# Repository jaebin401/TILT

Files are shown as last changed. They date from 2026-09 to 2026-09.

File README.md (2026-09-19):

# TILT

> Two-legged Iterative Locomotion Testbed

A compact 6-DoF biped robot platform for iterative locomotion experiments.

<p align="center">
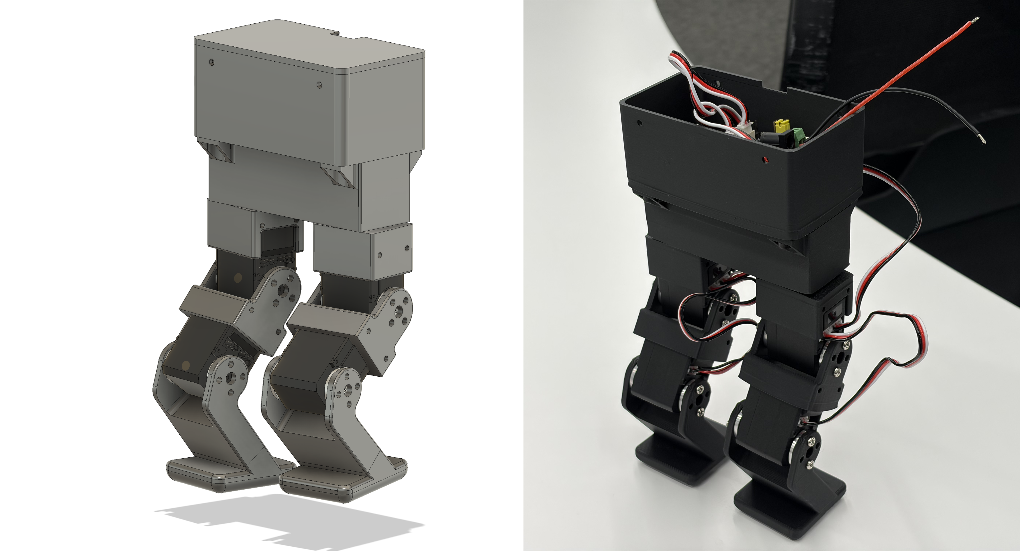
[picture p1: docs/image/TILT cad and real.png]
TILT MK1 CAD model
  
</p>

## Overview

TILT는 소형 이족보행 로봇의 기구 설계, 서보 제어, 보행 알고리즘을 반복적으로 실험하기 위한 로봇 프로젝트입니다.

Apple Developer Academy Challenge 6의 Physical AI Pet 프로젝트에서 보행 가능성을 검증하기 위해 시작했지만, 특정 캐릭터에 종속되지 않는 독립적인 로봇 플랫폼으로 발전시키는 것을 목표로 합니다.

## Goals

- ESP32-S3 기반 실시간 로봇 제어
- STS3215 버스 서보를 이용한 6자유도 하체 구현
- 모델 기반 관절 궤적과 보행 시퀀스 개발
- 평평한 실내 바닥에서 전진, 정지, 재출발 및 완만한 회전
- CAD와 펌웨어를 함께 관리하는 재현 가능한 로봇 프로젝트 구축
- 향후 센서 피드백과 균형 제어를 추가할 수 있는 구조 마련

## Hardware

| Component | Specification |
| --- | --- |
| Controller | ESP32-S3 |
| Actuator | 6 × Feetech STS3215-C001 |
| Servo interface | Waveshare Bus Servo Adapter (A) |
| Degrees of freedom | 6 DoF, 3 per leg |
| Communication | UART, BLE |
| Current prototype | TILT-P0 |

## Repository Structure

```text
TILT/
├── CAD/          # Mechanical source files and manufacturing exports
├── firmware/     # ESP32-S3 firmware
├── hardware/     # BOM, wiring, pinout and power documentation
├── tools/        # Servo setup and gait development utilities
└── docs/         # Architecture, assembly, calibration and experiment notes
```

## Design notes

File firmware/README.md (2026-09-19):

# TILT Firmware

TILT의 ESP32-S3 펌웨어 구조와 각 디렉토리의 책임을 정의합니다.

현재 단계에서는 모듈의 경계만 먼저 정리하며, ESP-IDF 프로젝트 설정과 C++ 구현은 이후 작업에서 추가합니다.

## Directory Structure

```text
firmware/
├── main/                       # 애플리케이션 진입점과 모듈 조립
├── components/
│   ├── tilt_core/              # 공통 타입과 로봇 설정
│   │   └── include/tilt/core/
│   ├── tilt_motion/            # 모델 기반 보행과 관절 목표 생성
│   │   └── include/tilt/motion/
│   ├── tilt_sts3215/           # STS3215 버스 서보 통신
│   │   └── include/tilt/sts3215/
│   ├── tilt_sg90/              # SG90 PWM 출력
│   │   └── include/tilt/sg90/
│   ├── tilt_safety/            # 명령 검증과 안전 상태 관리
│   │   └── include/tilt/safety/
│   ├── tilt_actuators/         # 액추에이터 명령 분배와 실행
│   │   └── include/tilt/actuators/
│   └── tilt_expression/        # 귀와 팔의 동작 생성
│       └── include/tilt/expression/
└── tests/
    ├── host/                   # 하드웨어 없이 실행하는 테스트
    └── hardware/               # 실제 ESP32와 액추에이터를 사용하는 테스트
```

각 컴포넌트의 공개 헤더는 `include/tilt/<component>/`에 둡니다. 구현 파일과 컴포넌트별 CMake 설정은 해당 컴포넌트의 루트에 배치합니다.

## Component Responsibilities

### `main`

펌웨어의 진입점입니다. 컴포넌트를 초기화하고 실행 태스크를 시작합니다.

하드웨어 제어나 보행 로직을 직접 구현하지 않고, 필요한 모듈을 조립하는 역할만 담당합니다.

### `tilt_core`

다른 컴포넌트가 함께 사용하는 타입과 설정을 정의합니다.

- 관절 식별자
- 관절 목표값과 현재 상태
- 관절별 위치 및 속도 제한
- 오류 코드
- 로봇 전체 설정

ESP-IDF의 UART, PWM 같은 하드웨어 기능에 의존하지 않는 것을 원칙으로 합니다. 각도 단위는 라디안, 시간 단위는 초를 기본으로 사용합니다.

### `tilt_motion`

TILT의 모델 기반 보행을 계산하고 다리 관절의 목표값을 생성합니다.

- LIPM과 같은 단순화된 동역학 모델
- CoM과 ZMP 기준값 계산
- 다리의 순기구학과 역기구학
- 보행 단계와 지지 상태 관리
- swing foot 궤적 생성
- MPC 또는 단순화된 궤적 추종 제어

초기에는 하나의 컴포넌트로 관리하며 구현이 커지면 내부를 `model`, `kinematics`, `planning`, `control` 영역으로 나눕니다. 물리 모델과 제어기의 경계가 충분히 커질 경우 별도 컴포넌트로 분리할 수 있습니다.

이 컴포넌트는 하드웨어를 직접 제어하지 않습니다. 계산 결과를 `JointTarget`으로 출력하고 안전 계층에 전달합니다.

### `tilt_sts3215`

ESP32-S3와 Waveshare Bus Servo Adapter 사이의 UART 통신과 STS3215 프로토콜을 담당합니다.

- 패킷 인코딩과 디코딩
- 서보 위치, 속도, 가속도 명령
- 현재 위치와 상태 읽기
- 통신 오류와 응답 시간 초과 처리

서보의 raw position과 레지스터 주소는 이 컴포넌트 밖으로 노출하지 않습니다.

### `tilt_sg90`

SG90 서보를 구동하기 위한 PWM 출력을 담당합니다.

- 각도와 PWM duty 변환
- 출력 범위 제한
- 귀와 팔에 연결된 채널 관리

표정이나 제스처의 의미는 해석하지 않고, 전달받은 목표 각도만 실행합니다.

### `tilt_safety`

액추에이터로 전달되기 전의 모든 명령을 검증하고 로봇의 안전 상태를 관리합니다.

- 관절 위치 및 속도 제한
- 비정상 수치와 오래된 명령 거부
- 급격한 목표값 변화 제한
- `Disarmed`, `Armed`, `Fault` 상태 관리
- 오류 발생 시 안전 정지와 fault latch

보행, 귀, 팔을 포함한 모든 움직임은 이 계층을 통과해야 합니다.

### `tilt_actuators`

검증된 관절 목표값을 실제 액추에이터 드라이버로 전달합니다.

- 다리 관절은 `tilt_sts3215`로 전달
- 귀와 팔 관절은 `tilt_sg90`으로 전달
- 하드웨어 초기화와 출력 주기 관리
- 액추에이터 상태 수집

여러 태스크가 드라이버를 동시에 호출하지 않도록 실제 하드웨어 접근의 단일 진입점 역할을 합니다.

### `tilt_expression`

귀와 팔을 이용한 자세, 제스처, 동작 시퀀스를 생성합니다.

이 컴포넌트는 PWM을 직접 출력하지 않고 논리적인 관절 목표값을 생성합니다. 생성한 목표값은 안전 검증을 거쳐 `tilt_actuators`로 전달됩니다.

## Command Flow

```text
Gait command                  Expression command
     │                                │
     ▼                                ▼
tilt_motion                  tilt_expression
     │                                │
     └─────────── JointTarget ────────┘
                      │
                      ▼
             tilt_safety validation
                      │
                      ▼
              tilt_actuators routing
                  │           │
                  ▼           ▼
         tilt_sts3215     tilt_sg90
                  │           │
                  ▼           ▼
              Leg servos   Ear / arm servos
```

상위 로직은 하드웨어 드라이버를 직접 호출하지 않습니다. `JointTarget`을 생성하고 안전 계층과 액추에이터 관리 계층을 통해서만 움직임을 요청합니다.

## Dependency Rules

```text
tilt_core
├── tilt_sts3215
├── tilt_sg90
├── tilt_safety
├── tilt_motion
└── tilt_expression

tilt_actuators
├── tilt_core
├── tilt_safety
├── tilt_sts3215
└── tilt_sg90

main
└── application components
```

- `tilt_core`는 다른 TILT 컴포넌트에 의존하지 않습니다.
- 드라이버는 상위 제어 로직에 의존하지 않습니다.
- `tilt_safety`는 특정 액추에이터 드라이버에 의존하지 않습니다.
- 컴포넌트 사이에서는 공개 헤더만 사용합니다.
- 순환 의존성을 만들지 않습니다.

## Tests

### `tests/host`

일반 컴퓨터에서 실행할 수 있는 순수 로직 테스트를 둡니다. 단위 변환, 명령 제한, 상태 전이와 같이 실제 하드웨어가 필요하지 않은 기능을 우선 검증합니다.

### `tests/hardware`

ESP32-S3와 실제 액추에이터가 필요한 검증 코드를 둡니다. 테스트마다 필요한 배선, 전원 조건, 실행 순서와 예상 결과를 함께 기록합니다.

## Planned Extensions

센서 피드백과 iPhone 연동을 구현할 때 다음 컴포넌트를 같은 원칙으로 추가합니다.

- `tilt_estimation`: IMU와 관절 피드백을 이용한 상태 추정
- `tilt_ble`: iPhone 명령 수신과 텔레메트리 전송

새 컴포넌트는 책임과 공개 인터페이스가 정해진 뒤 디렉토리를 추가합니다.

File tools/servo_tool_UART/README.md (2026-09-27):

# TILT 서보 셋업 / 캘리브레이션 툴

`tilt_config.h` 의 TODO 항목을 실측으로 채우는 도구. 모든 결과는 **그대로 붙여넣을 수 있는 C 코드**로 출력된다.

| config 항목 | 채우는 툴 |
|---|---|
| `ZERO_TICK[]` | `j` 정밀 조그 → `z` |
| `JOINT_SIGN[]` | `s` 회전 부호 판별 |
| `JOINT_LIMIT[]` | `l` 가동범위 탐색 |
| `SERVO_UART_BAUD` | `b` 보레이트 스캔 |

## 위치

```
TILT/
├── firmware/
│   └── components/
│       ├── tilt_config/
│       └── tilt_sts3215/
└── tools/
    └── servo_tool_UART/     ← 이 프로젝트
```

루트 `CMakeLists.txt` 의 `EXTRA_COMPONENT_DIRS` 가
`../../firmware/components` 를 가리키므로, 이 디렉토리에서 바로 빌드하면
공용 컴포넌트가 딸려 온다.

## 빌드

```bash
cd tools/servo_tool_UART
idf.py set-target esp32s3
idf.py -p /dev/tty.usbmodemXXXX flash monitor
```

`Ctrl + ]` 로 모니터 종료.

## tilt_sts3215 연결 방식

```cpp
tilt::sts3215::Sts3215Bus bus{config};
bus.initialize();
bus.ping(id);
bus.readPosition(id, tick);
bus.writePosition(id, tick, speed);
bus.setTorque(id, enabled);
bus.setBaudRate(baud);
```

`main.cpp` 상단의 얇은 래퍼가 기존 도구 호출을 이 실제 API로 연결한다.

## 저장 정책

**진실 공급원은 `tilt_config.h` 하나뿐이다.**

NVS 는 캘리브레이션 도중 리셋·정전으로 작업이 날아가지 않게 하는 임시 스크래치일 뿐이다.
부팅 시 NVS 값이 있으면 그걸 쓰고 그 사실을 로그로 알린다.

캘리브레이션이 끝나면:
1. 출력된 배열을 `tilt_config.h` 에 붙여넣고
2. `c` 로 NVS 스크래치를 비운다

이 두 단계를 하지 않으면 "코드에 적힌 값"과 "로봇이 실제로 쓰는 값"이 갈라진다.

## 영점 잡는 순서

1. **`s` 부호 판별** — 먼저 해야 조그 화면의 DH theta 부호가 맞게 나온다
2. **`o` 엔코더 모니터** — 토크를 풀고 손으로 대략 영점 자세를 만든 뒤 `z`
3. **`j` 정밀 조그** — FINE(1 tick = 0.088deg)로 마무리, DH theta 가 0.00 에 수렴하면 `z`
4. **`0` zero pose 이동** — config 의 `[0, -20, +20]` 으로 이동해 검증
   - 발판이 지면과 평행한가
   - 접지점이 Hip Yaw 축 바로 아래(x=0)인가
   - 지면 ~ torso 원점 높이가 약 104mm 인가
5. **`l` 가동범위 탐색** — 마지막에. 영점이 확정돼야 각도 값이 의미를 가진다

### 각 관절의 DH theta = 0 자세

| 관절 | 영점 자세 |
|---|---|
| Hip Yaw | 발끝이 정면(+x) |
| Hip Pitch | 허벅지가 수직 |
| Knee Pitch | 정강이가 허벅지와 일직선 |

`zero pose` 인 `[0, -20, +20]` 과 혼동하지 말 것. 영점은 **DH theta = 0** 인 자세이고,
zero pose 는 거기서 허벅지를 20deg 앞으로 기울이고 무릎을 20deg 굽힌 **운용 기본자세**다.

### DH + 방향

| 관절 | + 방향 |
|---|---|
| Hip Yaw | 발끝이 왼쪽으로 |
| Hip Pitch | 다리가 뒤로 스윙 |
| Knee Pitch | 무릎이 굽음 |

좌우 다리 모두 같은 정의를 쓴다. 거울 반전은 `JOINT_SIGN` 이 흡수한다.

## 안전

- 서보 전원은 손 닿는 곳에 두고, 언제든 끌 수 있게 한다
- `space` = 전체 토크 OFF (어느 화면에서든)
- 부팅 시 절대 위치 명령을 보내지 않는다 — 현재 위치를 READ 해서 기준으로만 삼음
- `s` 부호 판별과 `0` zero pose 이동은 **공중에 매단 상태**에서 할 것
- `l` 가동범위 탐색은 다리끼리 부딪히기 직전까지만. 스탠스 폭이 72.4mm 라 Hip Yaw 안쪽 여유가 적다

## 툴 목록

| 키 | 기능 |
|---|---|
| `p` | ID 스캔 (0~253) |
| `b` | 보레이트 스캔 |
| `j` | 정밀 조그 (q/a w/s e/d = 왼쪽, r/f t/g y/h = 오른쪽, `m` 스텝 토글, `i` 상태표, `z` 영점 확정) |
| `o` | 토크 해제 + 엔코더 실시간 모니터 (`z` 로 영점 확정) |
| `l` | 가동범위 탐색 → `JOINT_LIMIT` 출력 |
| `s` | 회전 부호 판별 → `JOINT_SIGN` 출력 |
| `0` | zero pose 로 천천히 이동 |
| `v` | 현재 작업값 배열 전부 출력 |
| `c` | NVS 스크래치 비우기 |
| `t` | 전체 토크 ON/OFF 토글 |
| `h` | 메뉴 |
| `space` | 비상정지 |

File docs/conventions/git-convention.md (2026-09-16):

# TILT Git Convention

## 1. Branch Strategy

TILT는 다음 브랜치 구조를 사용한다.

```text
feat/*  ──┐
fix/*   ──┤
docs/*  ──┼── Pull Request ──> dev ── Release PR ──> main
chore/* ──┤
test/*  ──┘
```

### main

조립, 시연 또는 배포할 수 있는 안정 상태를 보관한다.

- 직접 Push하지 않는다.
- `dev`에서 생성한 Pull Request만 병합한다.
- 펌웨어 빌드와 필요한 하드웨어 검증을 통과해야 한다.
- TILT MK 버전 또는 주요 마일스톤 단위로 갱신한다.
- Force Push하지 않는다.

### dev

다음 안정 버전을 준비하는 통합 브랜치다.

- 모든 작업 브랜치는 최신 `dev`에서 생성한다.
- 작업 브랜치의 Pull Request를 통해 변경을 반영한다.
- 직접 Push와 Force Push를 지양한다.
- 통합 후 정상 동작이 확인되면 `main`으로 Release PR을 생성한다.

### 작업 브랜치

| Prefix | 용도 | 예시 |
| --- | --- | --- |
| `feat/` | 새로운 기능이나 기구 추가 | `feat/servo-zero-position` |
| `fix/` | 기존 동작 또는 설계 오류 수정 | `fix/servo-id-conflict` |
| `docs/` | 문서 작업 | `docs/assembly-guide` |
| `chore/` | 저장소 설정과 개발 환경 | `chore/platformio-setup` |
| `test/` | 하드웨어, 제어 방식 또는 설계 실험 | `test/gait-sequence` |

브랜치 이름은 영문 소문자와 하이픈을 사용한다.

한 브랜치에서는 하나의 명확한 작업만 진행한다.

`test/*` 브랜치는 실험 결과를 검증하고 정리하기 위한 브랜치다. 실험 결과를 제품 코드에 반영하려면 불필요한 임시 코드를 제거한 뒤 `dev`를 대상으로 Pull Request를 생성한다. 폐기한 실험은 결과와 판단 근거만 문서로 남길 수 있다.

## 2. Standard Workflow

작업을 시작하기 전에 최신 `dev`를 가져온다.

```bash
git switch dev
git pull --ff-only origin dev
git switch -c feat/servo-zero-position
```

작업 후 원격 저장소에 Push한다.

```bash
git push -u origin feat/servo-zero-position
```

Pull Request 방향은 다음과 같다.

```text
base: dev
compare: feat/servo-zero-position
```

병합된 작업 브랜치는 삭제한다.

## 3. Commit Convention

기본 형식:

```text
<type>(<scope>): <subject>
```

예시:

```text
feat(firmware): add servo ping command
feat(cad): add MK1 hip bracket
fix(firmware): prevent duplicate servo IDs
docs(hardware): document servo wiring
chore(repo): configure initial repository
```

### Type

| Type | 의미 |
| --- | --- |
| `feat` | 새로운 기능, 동작 또는 기구 추가 |
| `fix` | 잘못된 동작이나 설계 수정 |
| `refactor` | 동작 변화 없는 코드 구조 개선 |
| `docs` | 문서 추가 및 수정 |
| `test` | 테스트 추가 및 수정 |
| `chore` | 저장소, 빌드, 개발 환경 설정 |
| `revert` | 기존 변경 되돌리기 |

### Scope

| Scope | 적용 대상 |
| --- | --- |
| `firmware` | ESP32-S3 펌웨어 |
| `cad` | 기구 설계 원본과 출력 파일 |
| `hardware` | 배선, 전원, BOM |
| `tools` | 서보 설정과 보행 개발 도구 |
| `docs` | 일반 문서 |
| `repo` | 저장소 전체 설정과 구조 |

### Subject 규칙

- 영어로 작성한다.
- 소문자로 시작한다.
- 동사 원형으로 시작한다.
- 문장 끝에 마침표를 사용하지 않는다.
- 가능하면 72자 이내로 작성한다.
- `update`, `change`, `work`처럼 모호한 표현만 사용하지 않는다.
- 하나의 Commit에는 하나의 논리적 변경만 포함한다.

## 4. Pull Request

Pull Request 제목도 Commit과 같은 형식을 사용한다.

```text
feat(cad): add MK1 hip bracket
fix(firmware): prevent servo overtravel
```

본문에는 다음 내용을 작성한다.

```markdown
## 작업 내용

- 무엇을 구현하거나 수정했는지 작성한다.

## 변경사항

- 주요 파일과 구조 변경을 작성한다.

## 확인 사항

- [ ] 관련 빌드 또는 파일 열기 성공
- [ ] 실제 하드웨어 또는 CAD 동작 확인
- [ ] 관련 없는 파일이 포함되지 않음
- [ ] 임시 파일과 빌드 결과물이 포함되지 않음

## 참고 자료

- 사진, 영상, 관련 문서 또는 이슈
- 없다면 `없음`
```

가능하면 다른 작업자 한 명이 검토한 후 병합한다.

작업 브랜치에서 `dev`로 병합할 때는 `Squash and merge`를 사용한다.

`dev`에서 `main`으로 승격할 때는 `Create a merge commit`을 사용한다.

## 5. Verification

### Firmware

- 프로젝트가 정상적으로 빌드되는가
- 서보 ID와 보드 설정이 올바른가
- 관절 제한을 벗어나는 명령이 없는가
- 실제 장비 테스트 결과를 PR에 기록했는가

### CAD

- 원본 파일이 정상적으로 열리는가
- STEP 또는 3MF로 정상적으로 내보낼 수 있는가
- 부품 간 간섭을 확인했는가
- 출력 방향과 revision을 확인했는가

### Repository

- 빌드 결과물과 개인 설정이 포함되지 않았는가
- `.DS_Store`와 임시 파일이 포함되지 않았는가
- 비밀번호, 토큰 또는 개인 환경 설정이 포함되지 않았는가

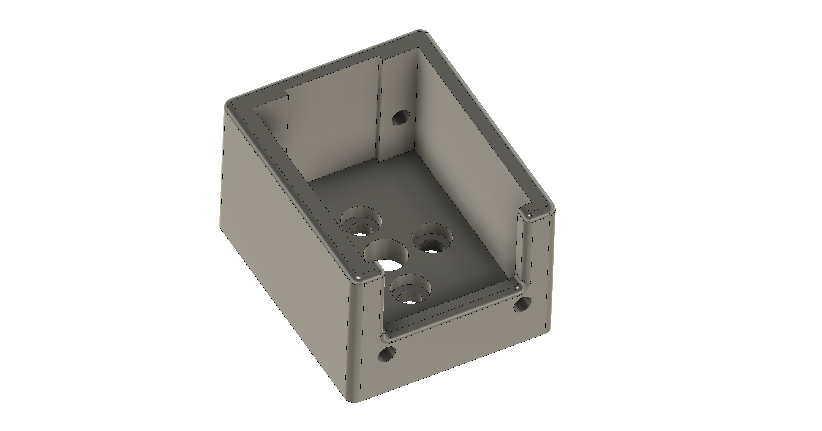
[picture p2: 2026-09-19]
CAD/images/hip pitch mount.png

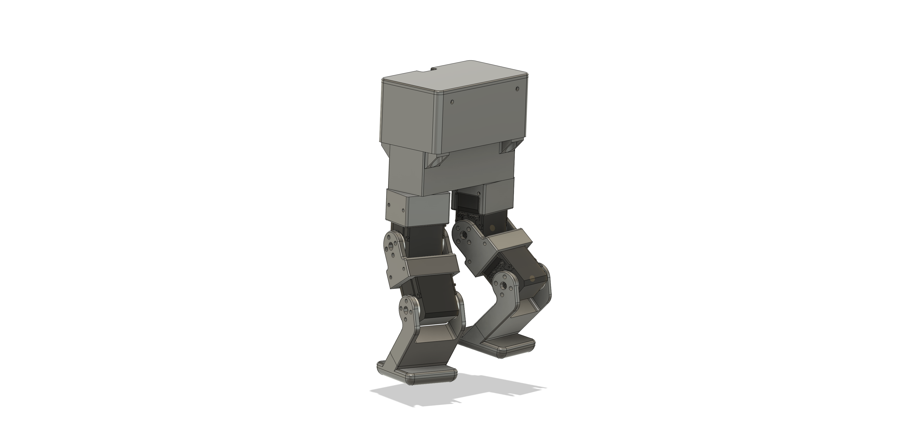
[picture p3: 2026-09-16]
docs/image/TILT mk1.png

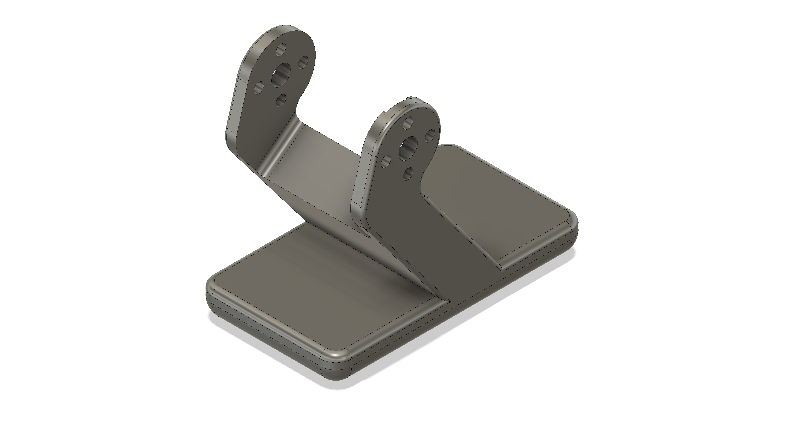
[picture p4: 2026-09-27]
CAD/images/calf-foot v3.png

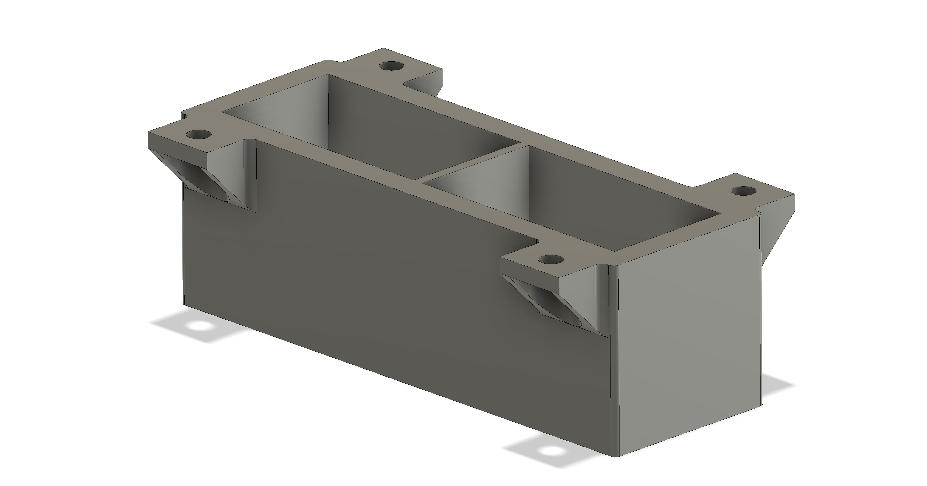
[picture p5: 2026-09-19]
CAD/images/hip yaw mount.png

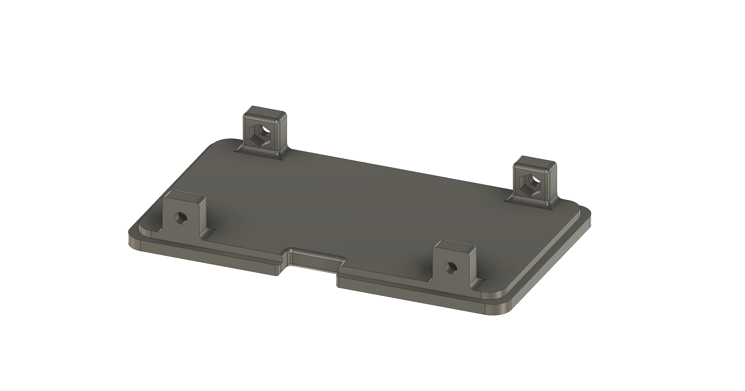
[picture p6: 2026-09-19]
CAD/images/torso lid.png

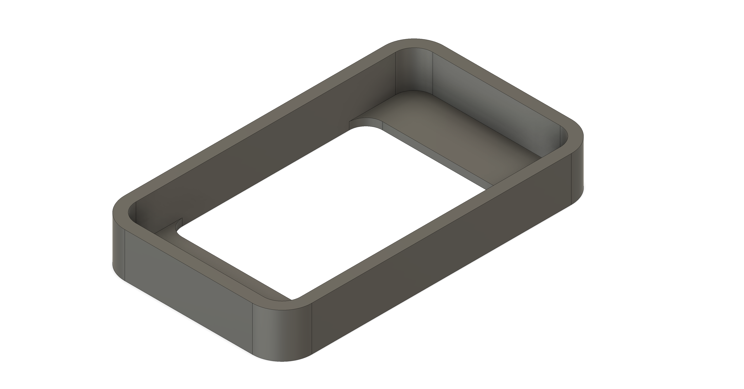
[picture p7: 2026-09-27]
CAD/images/calf-foot sharpener.png

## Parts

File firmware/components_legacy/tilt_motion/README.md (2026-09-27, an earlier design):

# TILT Motion

`tilt_motion`은 하드웨어와 독립적으로 여섯 다리 관절의 Pose와 시간 기반 Motion Clip을 계산합니다.

## Responsibility

- 논리 관절각 기반 `JointPose` 정의
- 확정된 기본자세 제공
- 두 Pose 사이의 부드러운 위치·속도·가속도 궤적 계산
- 여러 키프레임으로 구성된 Motion Clip 샘플링
- 임의의 시작자세에서 Home Pose로 복귀하는 표준 Motion 제공
- torso 좌표계에서 발의 위치·속도·가속도 궤적 계산
- Hip부터 Ankle 고정점까지의 FK·도달 가능 검사·closed-form IK
- Double Support와 좌우 Swing의 무상태 보행 phase 계산
- 지지 Ankle을 고정한 단일 Biped Step 궤적 계산

이 컴포넌트는 서보 ID, STS3215 raw position, 캘리브레이션 오프셋, 좌우 모터 방향 반전, UART 또는 실제 명령 실행을 다루지 않습니다. 이러한 변환과 실행은 actuator 및 driver 계층의 책임입니다.

## Joint order

모든 각도는 라디안이며 Robot/Kinematics 논리 좌표계를 사용합니다.

| Index | Joint |
| ---: | --- |
| 0 | LEFT_HIP_YAW |
| 1 | LEFT_HIP_PITCH |
| 2 | LEFT_KNEE_PITCH |
| 3 | RIGHT_HIP_YAW |
| 4 | RIGHT_HIP_PITCH |
| 5 | RIGHT_KNEE_PITCH |

## Home Pose

ADR-008에서 확정한 각 다리의 기본자세 `[0°, -20°, +20°]`를 사용합니다.

```text
[0, -0.349066, +0.349066, 0, -0.349066, +0.349066] rad
```

좌우 다리는 같은 논리 부호를 사용합니다. 실제 모터의 대칭 방향은 driver 계층에서 처리합니다.

## Interpolation

`samplePoseTransition()`은 quintic smootherstep `6u⁵ - 15u⁴ + 10u³`을 사용합니다. 시작과 끝에서 속도와 가속도가 모두 0이고 내부 상태가 없으므로, 호출 순서와 관계없이 임의 시각을 동일하게 샘플링할 수 있습니다.

반환되는 `PoseSample`에는 다음 값이 함께 들어 있습니다.

- 논리 관절 위치 `pose.angle_rad`
- 논리 관절 속도 `velocity_rad_per_sec`
- 논리 관절 가속도 `acceleration_rad_per_sec2`
- 전체 Motion 완료 여부 `finished`

`sampleMotionState()`는 첫 구간을 `initial_pose`에서 첫 키프레임까지 보간하고 이후 키프레임을 순서대로 연결합니다. 마지막 구간 이후에는 마지막 Pose와 0 속도·0 가속도를 반환합니다. 위치만 필요한 호출자는 `interpolatePose()`와 `sampleMotion()` 편의 함수를 사용할 수 있습니다.

`sampleReturnHomeMotion()`은 아직 실제 제한이 검증되지 않은 임의 Pose를 추가하지 않고, 문서로 확정된 Home Pose까지의 궤적만 생성하는 첫 표준 Motion입니다. 이동 시간은 호출자가 지정합니다.

## Foot trajectory

`sampleFootTrajectory()`는 torso 좌표계(`x=전진`, `y=왼쪽`, `z=위`)에서 시작점과 목표점 사이를 이동합니다. 수평·기준 높이 이동은 quintic smootherstep을 사용하고, `clearance_mm`만큼의 상승과 하강도 각각 quintic으로 계산해 시작·정점·착지에서 속도와 가속도가 0이 되도록 합니다.

보폭, 발을 드는 높이와 이동 시간은 하드웨어 검증 전이므로 라이브러리에 임의 상수로 고정하지 않습니다. 호출자가 게이트 파라미터로 전달해야 하며, `clearance_mm = 0`이면 지지발의 torso 기준 이동에도 사용할 수 있습니다. 이 출력은 다음 단계의 IK 입력이며 그 자체로 관절 명령이 아닙니다.

## Leg kinematics

`forwardAnkleKinematics()`와 `inverseAnkleKinematics()`는 ADR-008의 `Hip Yaw → Hip Pitch → Knee Pitch` 체인에서 Ankle 고정점 O4까지 계산합니다. `tiltLegGeometry()`는 확정된 Hip y 오프셋 `±36.2 mm`와 허벅지·정강이 길이 `50 mm`를 제공합니다.

IK는 호출자가 지정한 Hip Yaw 평면 안에서 양(+)의 Knee 굽힘 해를 계산합니다. 목표점이 해당 평면 밖에 있거나 두 링크의 작업공간 밖이면 `std::nullopt`를 반환합니다. 따라서 뒤쪽 목표도 Hip Yaw를 180°로 뒤집지 않고 지정된 다리 평면 안에서 처리할 수 있습니다.

Ankle FK/IK API는 O4까지만 계산해 확정된 링크 모델과 접지점 가정을 분리합니다. 접지점 E가 필요한 호출자는 아래의 별도 `ContactKinematics`를 사용합니다.

`forwardRobotAnkleKinematics()`와 `inverseRobotAnkleKinematics()`는 이 계산을 좌우 여섯 관절의 `JointPose` 단위로 묶습니다. 이를 통해 하드웨어 없이 `JointPose → 양쪽 O4 위치 → JointPose` 왕복 오차를 검증할 수 있습니다.

`ContactKinematics`는 다음 작업을 진행하기 위해 ADR-008의 Home Pose O4 위치와 문서상 접지점 E를 이용해 `O4→E=(-17.101007, 0, -7.015366) mm`를 임시로 역산합니다. 이 값은 CAD 실측값이 아니며 `provisionalFootContactGeometry()` 한 곳에 격리되어 있습니다. 현재 값으로 Home Pose 접지점과 `JointPose ↔ 양쪽 접지점` 왕복 계산을 재현하며, 실측 후 해당 상수만 교체합니다.

## Gait phase

`sampleGaitPhase()`는 `Double Support → 첫 번째 Swing → Double Support → 반대쪽 Swing`을 한 cycle로 반복합니다. 현재 지지 상태, 스윙 다리, 다음 스윙 다리와 phase 내부 진행률을 반환하며 내부 상태를 갖지 않습니다. Double Support와 Swing 지속 시간 및 첫 스윙 다리는 호출자가 전달하므로, 아직 검증되지 않은 주기나 좌우 시작 순서를 라이브러리에 고정하지 않습니다.

`sampleBipedStep()`은 전달받은 양쪽 O4 위치 중 지지 Ankle을 고정하고 스윙 Ankle에 `sampleFootTrajectory()`를 적용합니다. 위치·속도·가속도를 모두 반환하며, 결과 위치는 `inverseRobotAnkleKinematics()`로 관절 Pose 변환과 도달 가능 여부를 확인할 수 있습니다.

`sampleBipedStepPose()`는 이 경로를 한 번에 실행해 `발 궤적 → IK → JointPose`를 반환합니다. Cartesian 목표가 해당 Hip Yaw 평면이나 링크 작업공간을 벗어나면 관절각을 임의로 clamp하지 않고 실패합니다.

실제 보행 계획용 `sampleContactStep()`과 `sampleContactStepPose()`는 같은 동작을 접지점 E 기준으로 수행합니다. 지지 접지점을 고정하고 스윙 접지점만 이동한 뒤, 임시 접지점 기하를 포함한 IK로 `JointPose`를 계산합니다.

유효하지 않은 duration, NaN, 무한대 또는 잘못된 Clip은 `std::nullopt`로 거부합니다. 이 계층의 출력은 이후 Adapter가 `JointTargetBatch`로 변환하고 Safety 검증을 통과해야 실제 액추에이터로 전달될 수 있습니다.

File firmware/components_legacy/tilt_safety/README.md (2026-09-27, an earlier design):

# TILT Safety

## Responsibility and coordinates

`tilt_safety` validates six-joint commands before actuator execution and maintains Safety/Fault state. `JointTargetBatch.angle_rad` contains Robot/Kinematics logical joint angles in radians:

| Index | Logical joint |
| --- | --- |
| 0 | LEFT_HIP_YAW |
| 1 | LEFT_HIP_PITCH |
| 2 | LEFT_KNEE_PITCH |
| 3 | RIGHT_HIP_YAW |
| 4 | RIGHT_HIP_PITCH |
| 5 | RIGHT_KNEE_PITCH |

Motor Zero and Robot Zero are different coordinates. STS3215 raw position 2047 represents Motor Zero, not a logical robot target. Servo ID mapping, raw-position conversion, calibration offsets, servo direction/mirroring, UART, and STS3215 protocol belong below Safety. Safety does not generate trajectories or execute actuator commands. The actual TILT joint position and velocity limits have not been measured/configured here; host tests use synthetic values only.

## Implemented behavior

- Position and required-average-velocity validators check all six joints atomically. One invalid joint fails the entire validation. Targets are neither clamped nor automatically modified.
- The velocity validator checks `abs(target - runtime_reference) / (duration_ms / 1000)` in rad/s. This is the required **average** velocity, not measured instantaneous servo velocity. Time-based firmware calculations use seconds; `JointTargetBatch` retains its agreed millisecond fields.
- E-STOP and `FaultReason` (`EmergencyStop`, `ServoCommunication`) use a latched bitmask. Undefined, zero, and combined reason values are ignored by the public Fault APIs.
- A reported Fault enters `SafetyState::Fault`, invalidates the boot reference, and blocks new commands. A condition-cleared report alone does not remove the Fault. Explicit recovery is also required; clearing the final Fault returns to `Disarmed`, never directly to `Armed`.
- `initializeBootReference()` stores a validated logical joint-position snapshot. A boot snapshot indicates initialization readiness; it is not the current-position reference supplied to velocity validation during motion. Fault recovery does not restore it. A fresh physical read and initialization are needed after recovery.
- `arm()` succeeds only from `Disarmed` when position limits, velocity limits, and a validated boot reference are all present. `disarm()` revokes execution permission but never clears a Fault.
- While `Armed`, the runtime-reference overload returns `Accepted` only after the target and current runtime reference are both inside all six position limits and the required-average-velocity check passes. The overload without a runtime reference always rejects.

`SafetyState::Fault` does not itself mean a servo has physically stopped. The integrated pose test performs best-effort torque-off through the actuator driver; a physical power cutoff remains necessary when communication has failed.

## Pending work

| Area | Status and missing contract |
| --- | --- |
| Joint acceleration limit | **BLOCKED:** signed current velocity, velocity trajectory, acceleration/deceleration ramp, and execution guarantee |
| Actual boot position read | **INTEGRATED FOR TEST:** `esp32_pose_test` reads all six STS3215 positions and maps raw feedback to logical radians before arming; physical calibration remains pending |
| Safe initial pose | **INTEGRATED FOR TEST:** current-position hold precedes torque-on, then Home is reached through the normal Motion/Safety/Actuator path; completion tolerance and physical validation remain pending |
| Servo communication watchdog | **PARTIAL:** pose execution faults and requests torque-off on a failed read/write; a periodic background watchdog and measured thresholds remain pending |
| Stale command rejection | **CONTRACT PENDING:** `timestamp_ms` clock domain, stamping point, current-time provider, and maximum age |
| Command stream timeout | **BLOCKED:** Armed/active-motion and INIT execution semantics, stream requirement, and threshold |
| Over-temperature and overload | **BLOCKED:** telemetry fields and units, thresholds, sampling, and hardware validation; existing Fault mechanism can be reused once reasons are defined |

## Testing and concurrency

`firmware/tests/host/` tests pure position/velocity validation, arming, E-STOP and Fault state, recovery, boot-reference state, mapping, and packet encoding without hardware. `firmware/tests/esp32_pose_test/` exercises the integrated hardware path. **Host test success does not demonstrate physical robot safety or actuator stop behavior.**

`SafetyController` is not thread-safe. If command, E-STOP, actuator-health, or watchdog tasks call it concurrently, the application must serialize calls or provide synchronization.

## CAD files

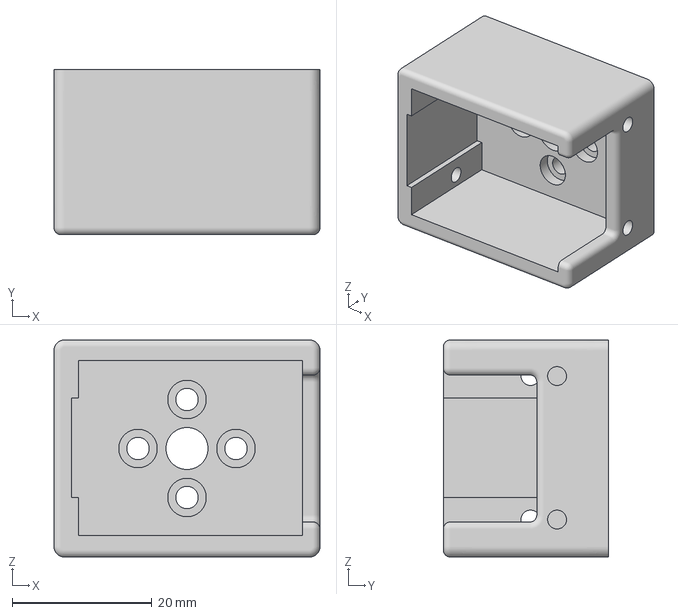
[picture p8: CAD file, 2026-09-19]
CAD/3mf files/tilt-hip-pitch-mount.3mf
38.0 x 23.6 x 31.0 mm

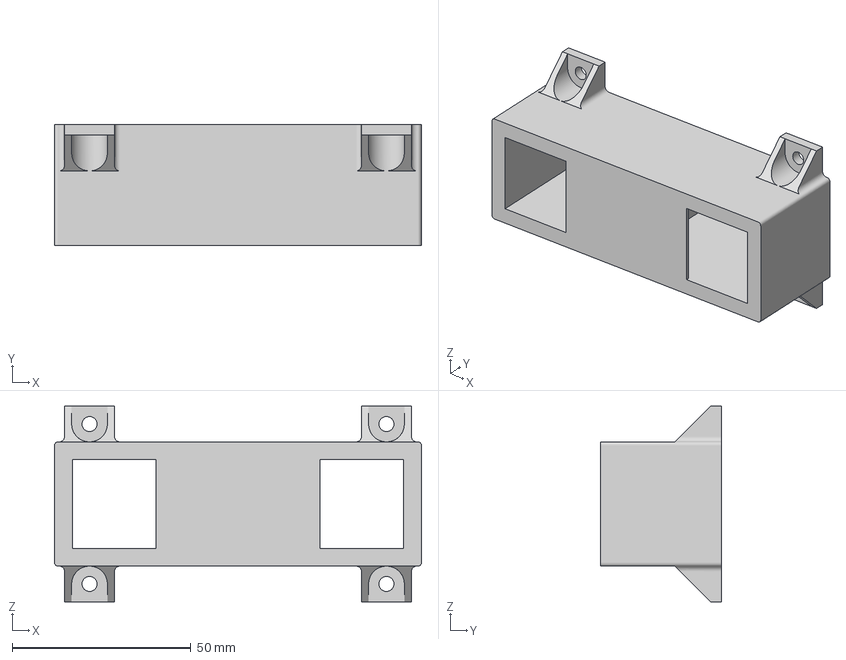
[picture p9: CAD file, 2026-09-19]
CAD/3mf files/tilt-hip-pitch-housing.3mf
102.8 x 33.9 x 54.8 mm

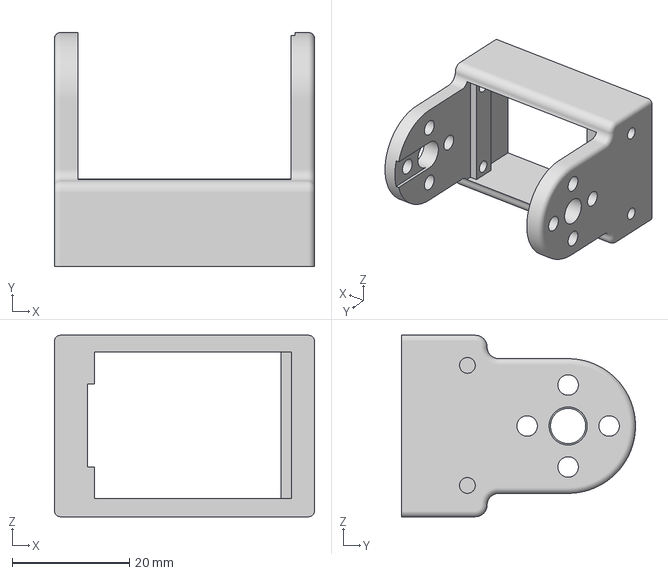
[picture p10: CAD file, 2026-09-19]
CAD/3mf files/tilt-thigh-mount.3mf
44.4 x 39.9 x 31.0 mm

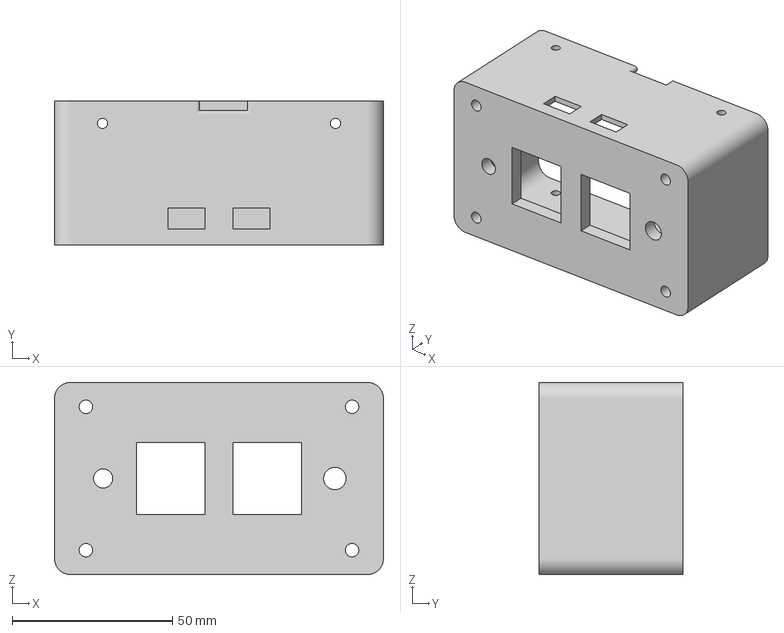
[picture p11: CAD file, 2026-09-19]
CAD/3mf files/tilt-torso-housing.3mf
102.8 x 45.0 x 60.0 mm

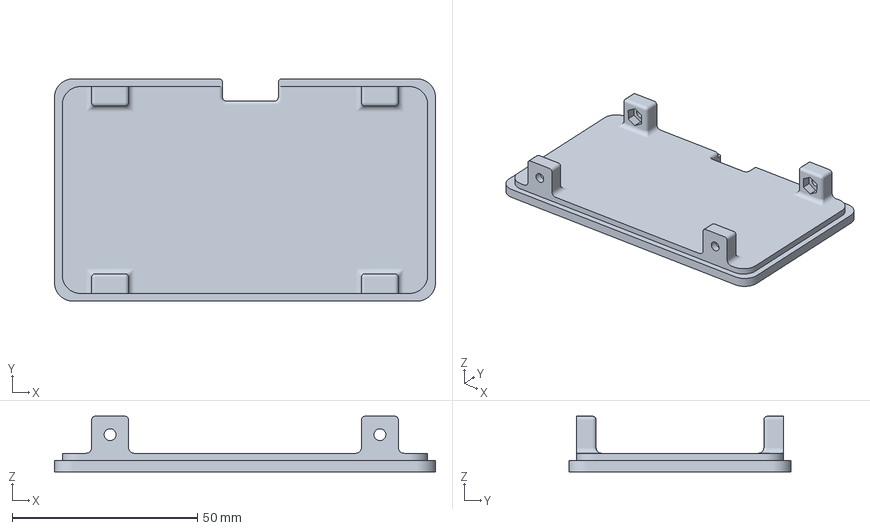
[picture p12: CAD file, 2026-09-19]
CAD/3mf files/tilt-torso-lid.3mf
102.8 x 60.0 x 15.0 mm

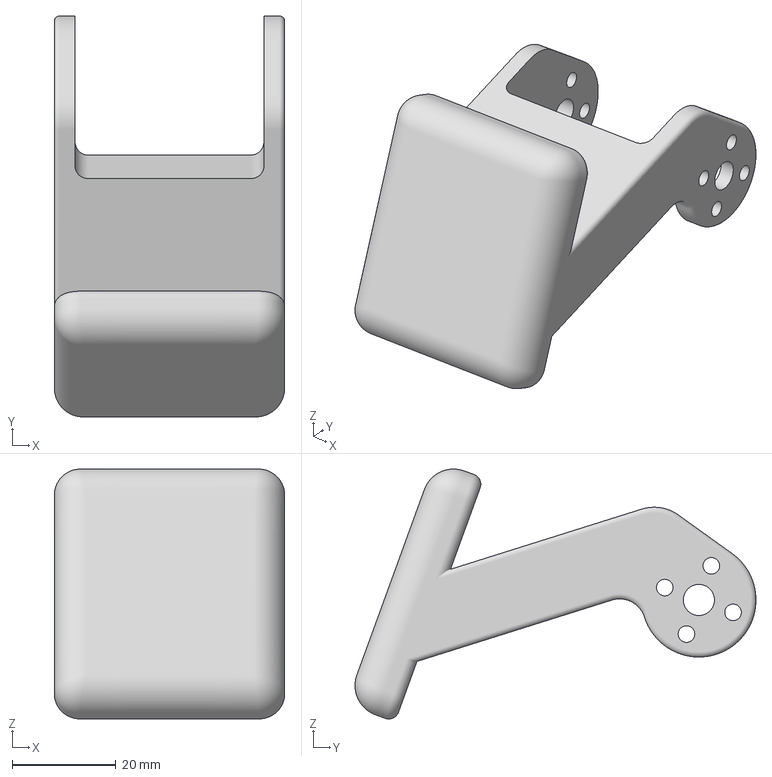
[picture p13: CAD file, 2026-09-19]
CAD/3mf files/tilt-calf-foot.3mf
44.4 x 77.3 x 48.1 mm

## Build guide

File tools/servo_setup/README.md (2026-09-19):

# STS3215 Servo Setup Tool

맥북에서 Waveshare Bus Servo Adapter (A)를 통해 STS3215-C001 서보의 통신 상태와 현재 위치를 확인하고, 혼을 조립하기 위한 기계적 중앙 위치 `2047`로 이동시키는 도구입니다.

이 도구는 ESP32 펌웨어가 아닙니다. 맥에서 직접 실행하는 일회성 설정 도구이며, 서보 검색, ID 변경, 기계적 중앙 정렬을 지원합니다. 영구 오프셋 보정은 아직 포함하지 않습니다.

## Safety

- STS3215-C001에는 안정화된 7.4V 전원을 사용합니다. 12V를 연결하지 않습니다.
- Waveshare 보드는 입력 전압을 조절하지 않으므로 입력 전압이 그대로 서보에 전달됩니다.
- USB 제어 시 Waveshare 점퍼를 `B` 위치에 둡니다.
- 처음에는 서보 한 개만 연결합니다.
- `set-id` 명령은 반드시 서보 한 개만 연결한 상태에서 실행합니다. 같은 ID의 서보 여러 개를 동시에 연결하지 않습니다.
- `center` 명령 전에 혼과 링크를 분리합니다.
- 외부 서보 전원을 즉시 끌 수 있는 상태에서 실행합니다.
- 서보가 움직이는 동안 축과 링크를 손으로 잡지 않습니다.

## Environment Setup

```bash
cd tools/servo_setup

python3 -m venv .venv
source .venv/bin/activate

python -m pip install --upgrade pip
python -m pip install -r requirements.txt
```

## Commands

### List serial ports

```bash
python servo_setup.py list-ports
```

Waveshare 보드는 일반적으로 다음과 비슷한 이름으로 나타납니다.

```text
/dev/cu.wchusbserialXXXX
/dev/cu.usbserial-XXXX
```

### Ping one servo

공장 초기 ID는 일반적으로 `1`이고 기본 통신 속도는 1,000,000 baud입니다.

```bash
python servo_setup.py ping \
  --port /dev/cu.wchusbserialXXXX \
  --id 1
```

### Find the current servo ID

서보 ID를 모르거나 `ping`에 응답하지 않으면 유효한 ID 범위 `0~253` 전체를 검색합니다. 이 명령은 서보를 움직이거나 설정을 변경하지 않습니다.

```bash
python servo_setup.py check-id \
  --port /dev/cu.wchusbserialXXXX
```

검색은 기본 통신 속도인 1,000,000 baud에서 실행되며 응답이 없는 경우 약 15초가 걸릴 수 있습니다. 다른 통신 속도를 확인하려면 `--baud`를 지정합니다.

```bash
python servo_setup.py check-id \
  --port /dev/cu.wchusbserialXXXX \
  --baud 500000
```

서보가 발견되면 ID와 모델 번호가 출력됩니다. 발견된 ID는 이후 `ping`, `read`, `center`, `release` 명령의 `--id`에 사용합니다.

### Change one servo ID

ID 변경은 EEPROM에 저장되므로 전원을 껐다 켜도 유지됩니다. 새 서보는 일반적으로 ID `1`이므로, 반드시 대상 서보 한 개만 연결한 뒤 실행합니다.

```bash
python servo_setup.py set-id \
  --port /dev/cu.wchusbserialXXXX \
  --current-id 1 \
  --new-id 11
```

도구는 다음 순서로 안전하게 변경합니다.

1. 기존 ID가 응답하는지 확인합니다.
2. 새 ID가 이미 사용 중인지 확인합니다.
3. `SET 1 11`과 같은 확인 문구를 요구합니다.
4. 토크를 해제하고 EEPROM 잠금을 해제합니다.
5. ID를 기록하고 새 ID로 EEPROM을 다시 잠급니다.
6. 새 ID는 응답하고 기존 ID는 응답하지 않는지 검증합니다.

성공하면 전원을 끄고 모터와 케이블에 관절 약어와 ID를 함께 표시합니다. 그다음 서보로 넘어갈 때는 새 서보만 연결하고 같은 과정을 반복합니다.

### Read the current position

```bash
python servo_setup.py read \
  --port /dev/cu.wchusbserialXXXX \
  --id 1
```

출력되는 각도는 중앙 위치 `2047`을 `0°`로 환산한 참고값입니다.

### Move to the mechanical center

```bash
python servo_setup.py center \
  --port /dev/cu.wchusbserialXXXX \
  --id 1
```

도구가 현재 위치와 예상 이동량을 출력합니다. 혼과 링크가 제거된 것을 다시 확인한 뒤 `CENTER`를 입력해야 실제 명령이 전송됩니다.

서보가 `2047 ± 10`에 도착하면 외부 서보 전원을 끄고 축을 움직이지 않도록 주의하면서 혼을 관절의 기계적 중립 위치에 체결합니다.

`center` 명령은 성공 후 토크를 유지합니다. 혼을 장착하기 전에 반드시 외부 서보 전원을 끕니다. 이동 중 오류가 발생하거나 `Ctrl+C`로 중단하면 도구가 토크 해제를 시도합니다.

### Release torque

```bash
python servo_setup.py release \
  --port /dev/cu.wchusbserialXXXX \
  --id 1
```

토크가 해제된 축은 손으로 움직일 수 있습니다. 토크가 활성화된 상태에서 축을 억지로 움직이지 않습니다.

## Joint Structure

각 다리는 몸통에서 발 방향으로 다음 관절 순서를 사용합니다.

```text
Hip Yaw → Hip Pitch → Knee Pitch
```

좌우는 관찰자가 아니라 로봇이 바라보는 방향을 기준으로 합니다. 권장 ID는 십의 자리로 다리를, 일의 자리로 관절 순서를 구분합니다.

| Label | ID | Joint |
| --- | ---: | --- |
| `LHY-11` | 11 | Left Hip Yaw |
| `LHP-12` | 12 | Left Hip Pitch |
| `LKP-13` | 13 | Left Knee Pitch |
| `RHY-21` | 21 | Right Hip Yaw |
| `RHP-22` | 22 | Right Hip Pitch |
| `RKP-23` | 23 | Right Knee Pitch |

새 서보 여섯 개가 모두 ID `1`이라면 각 모터를 하나씩 연결해 다음 순서로 할당합니다.

```text
1 -> 11  Left Hip Yaw
1 -> 12  Left Hip Pitch
1 -> 13  Left Knee Pitch
1 -> 21  Right Hip Yaw
1 -> 22  Right Hip Pitch
1 -> 23  Right Knee Pitch
```

모든 할당이 끝난 뒤 여섯 개를 함께 연결하고 최종 확인합니다.

```bash
python servo_setup.py check-id \
  --port /dev/cu.wchusbserialXXXX
```

최종 검색 결과에는 `11, 12, 13, 21, 22, 23`이 각각 한 번씩 나타나야 합니다.

## Mechanical Center vs Offset Calibration

현재 도구가 수행하는 작업은 서보를 raw position `2047`로 이동시킨 뒤 혼을 기계적 중립 위치에 체결하는 것입니다.

현재 축 위치를 새로운 중앙으로 저장하는 전자적 오프셋 보정은 수행하지 않습니다. 오프셋 보정은 전체 골격 조립 후 스플라인 간격으로 해결할 수 없는 오차가 있을 때 별도 절차로 진행합니다.

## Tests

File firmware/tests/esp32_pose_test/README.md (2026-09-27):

# ESP32-S3 통합 Pose Test

이 앱은 나중의 `main`과 같은 실행 경계를 미리 검증합니다.

`PoseInterpolator → SafetyController → ServoMapper → STS3215 UART → 6개 서보`

## 첫 실행 전

- 로봇을 스탠드에 고정해 두 발이 바닥에서 떨어진 상태로 시작합니다.
- 서보 전원 가까이에 물리 차단 수단을 둡니다. `!` 키의 토크 OFF는 통신이 끊기면 보장되지 않습니다.
- STS3215-C001에 맞는 별도 서보 전원을 사용하고 ESP32와 GND를 공통으로 연결합니다.
- Waveshare Bus Servo Adapter (A)는 UART 점퍼 A에 둡니다.
- 이 어댑터는 일반 UART 교차 배선이 아니라 `GPIO17 TX → Adapter TXD`, `GPIO18 RX → Adapter RXD`로 연결합니다.
- 서보 ID는 `11, 12, 13, 21, 22, 23`, 보레이트는 1 Mbps여야 합니다.

## 빌드와 실행

ESP-IDF 환경을 연 터미널에서:

```bash
source /Users/jae/esp/esp-idf/export.sh
cd firmware/tests/esp32_pose_test
idf.py set-target esp32s3
idf.py build
idf.py -p /dev/cu.usbmodemXXXX flash monitor
```

현재 저장소를 확인한 환경에는 `idf.py`가 PATH에 없었으므로, ESP-IDF export가 먼저 필요합니다. 실제 포트명은 연결 후 확인합니다.

## 안전한 검증 순서

부팅하면 항상 전체 토크 OFF, `DISARMED`로 시작합니다. 자동으로 Home으로 움직이지 않습니다.

1. `status`로 6개 ID의 응답과 raw 위치가 2047 근처인지 확인합니다.
2. `directions`로 논리 방향을 확인합니다. 기본값은 전부 `+1`이며 실제 조립 방향은 아직 확정값이 아닙니다.
3. 필요하면 `direction LHP -`처럼 바꿉니다.
4. `confirm`을 입력합니다. 확인값은 재부팅하면 사라집니다.
5. `arm`을 입력합니다. 현재 위치를 Goal로 먼저 기록한 다음 토크를 켜므로 과거 Goal로 튀는 것을 막습니다.
6. `joint LHY 1`처럼 관절 하나를 1도씩 움직여 모든 방향을 먼저 확인합니다. 한 번에 최대 5도입니다.
7. 방향이 틀리면 `disarm`, `direction ...`, `confirm`, `arm` 순서로 다시 진행합니다.
8. 여섯 관절이 확인된 뒤 `home`, `pose tall`, `pose crouch`, `pose yaw-left`, `pose yaw-right`를 실행합니다.

어느 때든 `!`는 소프트웨어 E-STOP과 전체 토크 OFF를 요청합니다. 이후에는 통신 상태를 해결하고 `recover`, `confirm`, `arm`을 다시 해야 합니다.

## Pose 상태

- `home`: ADR-008에서 확정된 `[0°, -20°, +20°]` 양쪽 다리 자세입니다.
- `tall`: `[0°, -15°, +15°]`
- `crouch`: `[0°, -30°, +35°]`
- `yaw-left`: 양쪽 Hip Yaw `+5°`, 나머지는 Home
- `yaw-right`: 양쪽 Hip Yaw `-5°`, 나머지는 Home

Home만 팀 문서의 확정 자세입니다. 나머지는 작은 범위의 하드웨어 검증용 초안이며 실제 안정 자세로 확정된 값이 아닙니다.

## 현재 임시 제한값

테스트 앱 안의 `PoseTestConfig.h` 한 곳에 모았습니다.

- Hip Yaw: `-10° ... +10°`
- Hip Pitch: `-35° ... +5°`
- Knee Pitch: `-5° ... +40°`
- 최대 논리 속도: `35°/s`
- raw soft limit: `1500 ... 2600`
- pose 이동 시간: 3초, 제어 주기: 100 ms

이 값은 실측 하드웨어 한계가 아닙니다. 첫 테스트 결과로 방향, 기구 충돌 범위, 속도, 가속도를 확인한 뒤 좁혀야 합니다.

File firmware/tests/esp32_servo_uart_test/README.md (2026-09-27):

# ESP32-S3 + Waveshare Bus Servo Adapter A (STS3215 x6) UART 제어 테스트

## 배선
| ESP32-S3 | Waveshare Bus Servo Adapter A |
|---|---|
| GPIO17 (TX) | TXD |
| GPIO18 (RX) | RXD |
| GND | GND |

**주의: 이 보드는 일반적인 UART 크로스 연결(TX↔RX)이 아니라 스트레이트(TX-TX, RX-RX)로 묶습니다.** Waveshare 공식 위키에 명시된 사항으로, 보드의 실크스크린 라벨이 호스트 기준으로 붙어 있기 때문입니다. 크로스로 연결하면 서보가 전혀 응답하지 않습니다.

- 보드의 점퍼는 **A 위치**(UART 모드)에 있어야 함
- 서보(STS3215)는 어댑터의 버스 서보 포트에 데이지체인으로 연결
- 서보 전원(6~12.6V)은 반드시 별도 파워서플라이에서 공급. ESP32의 5V/USB 전원으로 직접 구동하지 말 것 (ESP32는 USB로만 동작해도 되지만, 서보는 별도 전원 없이는 절대 응답도 동작도 하지 않음)
- 서보 통신은 UART1(GPIO17/18)로 분리. 콘솔(키보드 입력)은 네이티브 USB-Serial/JTAG 컨트롤러로 읽습니다 (이 보드는 별도 USB-UART 브릿지 칩 없이 네이티브 USB 하나로만 맥북과 연결되는 타입)

## 제어 방식
STS3215는 12bit 자기식 엔코더로 360도를 4096 step으로 표현하며, 최소 위치 분해능은 **0.088도(1 tick)** 입니다.
절대 각도로 바로 점프하지 않고, 키를 누를 때마다 정해진 스텝만큼만 이동합니다.

스텝 크기는 2단계이고 `m` 키로 토글합니다:

| 모드 | 스텝 | 각도 | 용도 |
|---|---|---|---|
| 정밀(FINE, 기본) | 1 tick | 0.088도 | 각도 정밀 캘리브레이션 |
| 빠름(COARSE) | 20 tick | 약 1.76도 | 구동 테스트 |

더 빠르게 하고 싶으면 `main.cpp`의 `COARSE_STEP` 값만 키우면 됩니다. 반대로 빠름 모드에서 움직임이 너무 급하면 `COARSE_GOAL_SPEED`를 1000 정도로 올려 서보 자체 속도를 제한할 수 있습니다.

부팅 시에도 목표 위치(GOAL_POSITION)를 먼저 쓰지 않고, 각 서보의 현재 위치를 `READ`로 먼저 확인한 뒤 그 값을 시작점으로 삼습니다. READ 응답을 못 받은 서보는 중앙값(2048, 약 180도)을 임시로 가정하니, 첫 몇 스텝은 실제 서보를 눈으로 보면서 확인하는 걸 권장합니다.

### 키 매핑 (Enter 불필요, 누르는 즉시 반응)
| 서보 | + | - |
|---|---|---|
| 11 | q | a |
| 12 | w | s |
| 13 | e | d |
| 21 | r | f |
| 22 | t | g |
| 23 | y | h |

- **m** : 스텝 모드 토글 (정밀 1 tick ↔ 빠름 20 tick)
- **p** : ID 스캔 (기본 0~253 범위, PING으로 실제 응답하는 서보 ID를 찾아서 출력)
- **b** : 보레이트 자동 스캔 (1M/500k/250k/128k/115200/76800/57600/38400/19200/9600을 순차적으로 바꿔가며 응답하는 값을 찾음. 찾으면 그 보레이트를 유지)
- **space** : 비상정지 (6개 서보 토크 전체 OFF)

`idf.py monitor`는 실행되는 동안 터미널을 raw 모드로 바꿔서, 키를 누르는 즉시 그 바이트를 타겟(USB-Serial/JTAG)으로 전달합니다. 그래서 별도로 Enter를 칠 필요 없이 코드가 1바이트씩 바로 읽어서 처리합니다.

## 사전 준비 (맥북)
1. ESP-IDF 설치 (v5.x 권장)
   ```bash
   git clone -b v5.3 --recursive https://github.com/espressif/esp-idf.git ~/esp/esp-idf
   cd ~/esp/esp-idf
   ./install.sh esp32s3
   . ./export.sh
   ```
   새 터미널을 열 때마다 `. ~/esp/esp-idf/export.sh` 로 환경을 다시 활성화해야 합니다.

## 빌드 및 실행
```bash
cd esp32_servo_uart_test
idf.py set-target esp32s3
idf.py build
```

ESP32-S3를 USB로 맥북에 연결한 뒤 포트 확인:
```bash
ls /dev/tty.usbmodem*   # 또는 /dev/tty.usbserial*
```

플래시 및 모니터 실행:
```bash
idf.py -p /dev/tty.usbmodemXXXX flash monitor
```

부팅 로그가 끝나면 바로 q/a/w/s/e/d/r/f/t/g/y/h 키로 서보를 움직여볼 수 있습니다.
서보가 반응이 없을 때는 우선 `b`로 보레이트부터 자동 스캔해보세요. 응답하는 보레이트를 찾으면 그 값을 유지한 채 멈추고, 그 자리에서 `p`로 ID도 바로 확인해볼 수 있습니다. 모든 보레이트에서도 응답이 없으면 보레이트 문제가 아니라 배선/전원/ID 설정 쪽을 의심해야 합니다.
`Ctrl + ]` 로 모니터를 종료합니다.

## 참고 / 주의사항
- 컨트롤 테이블 주소(Torque Enable=40, Goal Position=42, Goal Speed=46, Present Position=56)는 Feetech STS 계열 버스 서보에서 흔히 쓰이는 값을 기준으로 작성했습니다. STS3215(C001) 실제 동작이 다르면 데이터시트/메모리 맵으로 주소를 재확인하세요.
- Present Position READ 응답 파싱은 간단한 구현이라, 어댑터가 half-duplex라서 TX가 그대로 에코되어 돌아오는 구조라면 응답을 못 찾을 수 있습니다. 이 경우 로그에 READ 실패 경고가 뜨고 중앙값(2048)으로 대체되니, 실제 위치와 다를 수 있음을 감안하고 초기 스텝을 조심스럽게 확인하세요.
- 이 프로젝트는 콘솔 입력을 네이티브 USB-Serial/JTAG 컨트롤러로 읽습니다 (`console_input_init`). 만약 보드가 별도 USB-UART 브릿지 칩을 쓰는 구조라서 UART0(GPIO43/44)로 다시 바꾸고 싶다면, `console_input_init` 안을 이전의 `uart_driver_install(UART_NUM_0, ...)` 방식으로 되돌리면 됩니다.
- 서보 버스 보레이트는 STS3215 공장 출하 기본값인 1,000,000bps로 설정했습니다. 서보가 응답 없으면 이전에 보레이트를 바꾼 이력이 있는지 확인하세요.

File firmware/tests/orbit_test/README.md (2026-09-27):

# TILT orbit_test

H-LIP 관상면(P2, 순 좌우 이동 0) 궤도를 참고한 **제자리 발 들기 실험**이다.
전진 x 스텝, IK, IMU 자동 정지는 없다. 기존 테스트와 공용 컴포넌트는
수정하지 않는다. 실험은 물리적 서보 전원 차단 수단을 손 닿는 곳에 두고 한다.

## 빌드와 PC 검산

```bash
source /Users/jae/esp/esp-idf/export.sh
cd firmware/tests/orbit_test
idf.py set-target esp32s3
idf.py build
idf.py -p /dev/cu.usbmodemXXXX flash monitor
```

```bash
cmake -S firmware/tests/orbit_test/host_test -B /tmp/tilt-orbit-host-build
cmake --build /tmp/tilt-orbit-host-build
ctest --test-dir /tmp/tilt-orbit-host-build --output-on-failure
```

`OrbitModel.h`, `LegPose.h`, `Bezier.h`는 ESP 의존성이 없는 헤더다.
Fusion 실측 상수로부터 roll 반경·유효 높이·고유 지지 시간·예측 진폭을
계산한다. 모델의 예상치는 약 T*=320ms, roll 진폭 ±4.6°,
교대 각속도 65°/s, 스윙쪽 hip 상승 4.4mm이다. 이는 검증 대상인
예측치이지 TILT의 실측 보행 결과가 아니다.

## 필수 안전 순서

1. 부팅은 `DISARMED`, 토크 OFF, 자동 이동 없음이다. `status`로 6축 응답을
   확인하고, 로봇을 받친 상태에서 `arm`한다. `arm`은 현재 서보 위치를
   hold goal로 전송한 뒤 토크를 켠다.
2. 로봇을 **공중에 매단 상태**로 `check`를 실행한다. ID 11–13 블록이
   5mm 접힌 후, 실제 올라간 다리가 로봇 기준 왼쪽이면 `l`, 오른쪽이면
   `r`을 누른다. 원위치가 끝나면 똑바로 잡고 `tilt` + Enter를 입력한 뒤
   2초 동안 로봇 기준 왼쪽으로 기울인다. 결과가 현재 부팅에서 즉시
   적용된다. 재부팅 뒤에도 유지하려면 결과에 나온 `kSwapLegSides`와
   `kRollSign`을 `main/OrbitConfig.h`에 반영한다.
3. 로봇을 바닥에 내리고 `stand` (기본 96.5mm), `gait`, `r` 순서로
   똑바로 정지한 상태의 roll 기준을 잡는다. `r`은 움직이는 동안 거부된다.
4. `1` ROCK으로 시작한다. `space`를 눌러 공진 흔들기의 실측 반주기와
   roll p-p를 모델 예측(약 320ms, 9.2°)과 비교한다. 다르면
   유효 높이 또는 발판 안쪽 지지점 가정을 재검토한다.
5. `space`로 멈춘 뒤 `2` OPEN에서 슬로모션으로 발이 실제로 뜨는지 확인한다.
   `3` ORBIT은 이번 부팅에서 `check` 통과 전에는 시작할 수 없다.
   ORBIT에서 `e`로 에너지 조절을 켜고 워치독 횟수와 교대 각속도를 본다.

좌우 서보 블록의 실제 다리 대응은 미검증이다. 잘못 매핑하면 지지발을
들어 넘어질 수 있으므로 `check` 없이 바닥에서 보행을 시도하지 않는다.
ROCK/OPEN은 미확인 상태에서도 경고 후 허용하지만 안전하다는 뜻이 아니다.
IMU 읽기가 실패해도 자동 정지하지 않는다. ORBIT은 1.5T 워치독으로
교대를 계속한다. 사람이 `space`, `!`, 또는 물리적 전원 차단으로 멈춘다.

## 명령과 키

줄 단위 명령: `help`, `status`, `model`, `arm`, `disarm`, `recover`,
`check`, `tilt`(check 안내가 나온 뒤), `stand [height_mm] [lean_deg]`,
`gait`. `!`는 어떤 모드에서든 긴급 토크 OFF를 요청한다.

`gait`에서는 Enter 없이 한 키씩 입력한다.

| 키 | 동작 |
| --- | --- |
| `1` / `2` / `3` | ROCK / OPEN / ORBIT 선택 (정지 중) |
| space | 시작 / 정지 (정지 시 두 다리 nominal stand 복귀) |
| `[` / `]` | 한 발 지지 시간 T ∓/±10ms (0.20–0.50s) |
| `+` / `-` | Bézier lift 제어점 z_max ±0.5mm |
| `,` / `.` | 밀어주기 δ ∓/±0.5mm |
| `e` | ORBIT 에너지 조절 ON/OFF |
| `s` / `S` | STARTUP 높이차 ∓/±0.5mm |
| `r` | 정지 중 roll 기준 재설정 |
| `c` | 100Hz CSV ON/OFF |
| `m` / `v` | 모델 예측 / 현재 상태·측정 요약 |
| `q` | 결과 출력, nominal stand 복귀 후 줄 단위 콘솔 |

ROCK은 타이머 T로 양발 높이차만 번갈아 주며 발을 들지 않는다.
OPEN·ORBIT은 먼저 STARTUP에서 roll 진폭이 예측 진폭의 70% 이상인
반주기가 연속 두 번 나와야 SSP를 시작한다. 12사이클 안에 충족하지 못하면
경고하고 흔들기만 계속한다. OPEN은 타이머, ORBIT은 roll 영점 교차와
자이로 각속도로 지지발을 교대한다. ORBIT의 `e`는 교대 속도 오차에 따라
다음 SSP의 δ를 0–4mm 범위에서 조절한다.

명령 lift 정점은 Bézier 제어점의 약 0.875배이다. SSP 중간에 스윙 다리의
무릎 서보 **하나만** 읽어 실제 다리 접힘량을 계산한다. 출력의
`estimated clearance = 실제 접힘량 + D·sin(roll 피크)`는 **모델 기반
추정값이며, 발과 바닥 사이 간격을 실측한 값이 아니다.** 밀어주기에 따른
지지발 앞뒤 밀림도 δ·cot(a)의 추정치다. CSV는
`t_ms,mode,state,roll_deg,rate_deg_s,h_L,h_R,delta`를 매 10ms 출력하며,
켜져 있는 동안 반주기 텍스트 출력은 숨긴다.

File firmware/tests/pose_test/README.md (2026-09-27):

# TILT ESP32-S3 pose test

`pose_test` is a new, standalone hardware test for the current components:

`tilt_kinematics → JointMapper → Interpolator → tilt_sts3215 UART`

It deliberately does **not** depend on the old `tilt::core` or
`tilt::actuators` APIs. `../esp32_pose_test` is historical reference only and
is not built or modified by this project.

## Wiring and safety

- This adapter connection is **straight**, not crossed: `GPIO17 TX → Adapter
  TXD`, `GPIO18 RX → Adapter RXD`.
- Set the Waveshare Bus Servo Adapter (A) UART jumper to **A**.
- Use servo IDs `11, 12, 13, 21, 22, 23` at **1 Mbps**.
- Use a separate servo supply, share GND with the ESP32, and keep a physical
  servo-power disconnect within reach.
- Start with servo power disconnected. The `!` command requests torque OFF,
  but it cannot protect against a lost UART/power connection.

## Build and flash

```bash
source /Users/jae/esp/esp-idf/export.sh
cd firmware/tests/pose_test
idf.py set-target esp32s3
idf.py build
idf.py -p /dev/cu.usbmodemXXXX flash monitor
```

## Required first-run sequence

`ZERO_TICK` and `JOINT_SIGN` in `components/tilt_config/include/tilt_config.h`
are currently placeholders. Measure each joint with `tools/servo_tool` and
update those shared values before treating any IK result as physically valid.

1. Keep the robot suspended in a stand; do not begin on the floor.
2. Run `status` and confirm all six IDs respond.
3. Run `check` and confirm the measured zero pose.
4. Run `arm`; it reads all present positions and writes them as the hold goal
   before enabling torque.
5. Use `joint <name> <deg>` in increments no larger than 5° to verify each
   direction.
6. Try `home`, then `pose <name>`, then `ik`.

`body_x` causes a real forward/back shift. For floor testing, keep it at zero
and verify height changes first.

## Commands

| Command | Purpose |
| --- | --- |
| `help` | Show the command list. |
| `status` | Ping each servo and print raw/logical positions. |
| `check` | Compare encoder angles with ADR-008 zero pose. |
| `arm` / `disarm` | Enable torque after hold-goal capture / request torque OFF. |
| `!` | Immediate E-STOP request in every mode. |
| `recover` | ESTOP → DISARMED after all six servos respond; run `arm` again. |
| `home`, `pose <name>` | Interpolated move to a preset. |
| `joint <name> <deg>` | Relative single-joint jog (maximum ±5°). |
| `fk` | Calculate both feet from current encoder readings. |
| `ik` | Enter the torso-motion IK demonstration after interpolating home. |
| `stand` | Enter the floor-based stationary pitch-compensation test. |
| `rock` | Enter the floor-based left/right weight-shift test after confirmation. |
| `walk` | Enter the confirmed, IMU roll-triggered lift-and-step walk test. |

In IK mode: arrow keys or `W/A/S/D` move the torso, `m` toggles fine/coarse
steps, `0` returns to IK home, `v` compares encoder FK with the requested feet,
`q` exits back to home, and `!` E-STOPS. Unreachable or joint-limit-clamped IK
targets are rejected rather than sent to the servos.

## Stand compensation test

`stand` returns to home and starts with compensation **OFF**. Use it only on
the floor with both hands ready to catch the robot. The control loop calculates
pitch compensation every 30 ms while console status is limited to one line per
200 ms.

- `c`: toggle pitch compensation; `+` / `-`: adjust Kp by 0.5 mm/degree.
- `[` / `]`: adjust the low-pass coefficient by 0.05.
- Up/down arrows: change base height; `r`: reset roll and pitch zero.
- `0`: disable compensation and return `body_x` to zero.
- `t`: apply a +8 mm, 500 ms disturbance and record the following 2-second
  response, including peak pitch, settling time, residual, and sign reversals.
- `v`: print the current state; `q`: return to home; `!`: E-STOP.

## Rocking test

Unlike the earlier calibration steps, `rock` is meaningful only with both feet
on the floor. Keep both hands ready to catch the robot before confirming the
entry prompt. The test changes the two leg lengths in opposite directions while
keeping `body_x=0`; MPU roll is display/abort information only and is never fed
back into motion control. If the MPU6050 is unavailable, the mode remains usable
and displays `roll=--`, `pitch=--`.

- Arrow keys or `W/A/S/D`: change differential leg length or base height.
- `m`: toggle 0.5 mm / 2 mm steps; `0`: return differential length to zero.
- `f`: toggle the leg target generator. `FLAT` (the default) directly uses
  `[0, -a, +a]` to keep each foot horizontal; `IK` preserves the original
  free-foot-angle behavior and displays each target foot tilt.
- `1`: sweep from 0 to 14 mm with a 1.5 s hold at each 1 mm step.
- `2`: alternate the current non-zero magnitude left/right; `[` and `]` adjust
  its 150–2000 ms period in 50 ms steps. If the requested period is shorter
  than the velocity-limited move time, the period is expanded automatically.
- `k`: record the visually observed left/right foot-lift point.
- `r`: use the current IMU roll and pitch as the new zero; `v`: print current
  delta, leg lengths, target foot geometry, and absolute/relative attitude.
- `c`: toggle pitch/body-x compensation; `+` / `-`: adjust its Kp.
- `x`: toggle cycle-boundary roll recentering; `z`: toggle cycle-boundary roll
  amplitude tracking. Both roll compensators default to OFF.
- `q`: print the result and return home; `!`: immediate E-STOP.

Any key stops an automatic sequence and returns `delta` to zero. A target is
rejected without transmission if IK is unreachable or any logical joint limit
would be clamped. Automatic motion also stops if measured roll exceeds 20°.
Move duration is automatically extended from the largest joint-angle change so
the 180°/s speed guard remains a final fault barrier rather than a normal motion
limiter. Stopping alternating rocking prints roll/pitch peak-to-peak motion and
the final pitch residual, compensation state, roll-center movement, final
delta bias/scale, and body-x usage. It warns for dominant pitch oscillation,
possible backward drift, or saturated body-x authority. Roll bias and amplitude
scale update only at commanded-delta sign changes, never every control tick.
After returning to `delta=0`, a relative-roll residual over 1° warns that the
curved foot may not have returned to its original contact point.

## Walk test

`walk` returns home after a safety confirmation, then waits stopped with
`delta=14 mm`, `lift=0`, and `legx=0`. Entry is rejected unless valid MPU6050
roll/pitch data is available. Press space to start only after confirming that
stationary rocking is safe. The delta sign flips on a fixed open-loop period,
while relative roll selects the unloaded swing leg using separate entry and
release thresholds. The swing foot receives the additional lift and forward x;
the support foot moves backward. Every target uses IK only.

- Space starts/stops; stopping returns `delta`, `lift`, and `legx` to zero.
- Left/right arrows or `A/D` change `legx` by 1 mm within ±20 mm.
- Up/down arrows or `W/S` change base height by 0.5 mm.
- `+` / `-` change swing-foot `lift` by 1 mm within 0–14 mm.
- `,` / `.` change rocking `delta` by 1 mm within 0–24 mm.
- `[` / `]` change the rocking period by 25 ms within 150–800 ms.
- `;` / `'` change the roll entry threshold by 0.25°; release remains 1.2°.
- `c` toggles common pitch/body-x compensation; `r` resets roll/pitch zero.
- `0` returns both `lift` and `legx` to zero; `v` prints all parameters;
  `q` prints the result and returns home; `!` E-STOPS.

Swing entry occurs at ±2.5° and is held until roll returns inside ±1.2°. The
80 ms minimum prevents noise from cutting a swing short, while the 400 ms
maximum forces release if roll does not return. Output is limited to swing-leg
changes, including return to double support. The exit summary reports per-leg
swing counts and average duration, forced releases, suppressed early releases,
and rejected targets. It intentionally does not estimate forward distance from
the 6-axis IMU.

All compensation is disabled if relative roll or pitch exceeds 20°, or after
five consecutive IMU read failures. Walk stops after five consecutive IMU
failures because swing timing is no longer available. Targets that exceed the
workspace or logical joint limits are rejected instead of clamped and sent;
three consecutive rejections stop the walk.

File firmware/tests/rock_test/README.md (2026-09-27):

# TILT rock test

`rock_test`는 좌우 무게 이동과 한 발이 지면에서 온전히 떨어지는지를
분리해서 확인하는 독립 ESP-IDF 실험이다. 전진 보행은 하지 않는다. 기존
`pose_test`·`walk_test`나 공용 컴포넌트를 수정하지 않는다.

다리를 평행하게 접기 위해 hip pitch와 knee pitch를 같은 크기, 반대 방향으로
움직인다. `tilt_kinematics`의 IK는 사용하지 않는다. 발 목표 높이(mm)를
10ms마다 선형 보간하고, [ParallelLeg.h](main/ParallelLeg.h)의 수식으로
6축 관절각을 만든 뒤 한 개의 `syncWritePositions` 패킷으로 전송한다.

## 배선과 물리적 안전

- ESP32-S3 `GPIO17 TX → Adapter TXD`, `GPIO18 RX → Adapter RXD`로 직결한다.
- Waveshare Bus Servo Adapter (A)의 UART 점퍼를 A에 둔다.
- 서보 ID는 `11, 12, 13, 21, 22, 23`, 통신 속도는 1 Mbps다.
- 서보는 별도 전원을 사용하고 ESP32와 GND를 공유한다.
- 로봇을 바닥에 세우고 두 손으로 즉시 받칠 준비를 한다.
- 서보 전원을 즉시 끊을 수단을 손 닿는 곳에 둔다. `!`는 UART 통신이나
  전원 자체가 끊어진 경우를 대신할 수 없다.
- 부팅 시 `DISARMED`, 토크 OFF, 자동 이동 없음이다. `arm`은 현재 여섯
  위치를 읽어 hold goal로 먼저 쓴 뒤 토크를 켠다.
- 이 테스트에는 **IMU 각도에 의한 자동 정지가 없다.** 넘어지려 하면
  사람이 space 또는 물리적 전원 차단으로 멈춰야 한다.

높이 공간 보간만 사용하므로 `arm` 당시 자세가 평행 다리 자세에서 약 2°
이상 벗어나면 `stand`/`rock`을 거부한다. 이 경우 `disarm`하고 로봇을
ADR-008 zero 평행 자세 근처에 배치한 뒤 다시 `arm`한다. 임의의 비평행
자세에서 관절을 갑자기 평행 목표로 당기지 않기 위한 제한이다.

## 빌드

```bash
source /Users/jae/esp/esp-idf/export.sh
cd firmware/tests/rock_test
idf.py set-target esp32s3
idf.py build
idf.py -p /dev/cu.usbmodemXXXX flash monitor
```

기존 `firmware/tests/host_test`를 그대로 두기 위해 PC 검산은 이 프로젝트
안의 `host_test`에 독립 실행파일로 둔다.

```bash
cmake -S firmware/tests/rock_test/host_test -B /tmp/tilt-rock-host-build
cmake --build /tmp/tilt-rock-host-build
ctest --test-dir /tmp/tilt-rock-host-build --output-on-failure
```

PC 검산은 90–103.97mm 높이에서의 허벅지각·발 x 표, ADR-008 zero pose,
lean을 반영한 발판의 수평 각도를 확인한다.

## 명령

줄 단위 명령:

| 명령 | 동작 |
| --- | --- |
| `help` | 도움말 |
| `status` | 6축 ping, raw tick, 논리 각도 |
| `arm` / `disarm` | 현재 자세 hold 후 토크 ON / 토크 OFF |
| `recover` | E-STOP에서 DISARMED로 복구; 다시 `arm` 필요 |
| `!` | 모든 모드에서 E-STOP |
| `stand [h] [lean_deg]` | 양발을 같은 높이의 평행 자세로 2초 이동 |
| `rock` | 기준 stand 자세로 이동한 뒤 정지 상태의 rock 모드 진입 |

rock 모드에서는 Enter 없이 한 키씩 입력한다. 기본 패턴은 `PHASE6`이고,
정지 상태에서 `m`으로 `BRUTON`과 전환한다. 전환 시 해당 키 안내가 출력된다.

| 키 | 동작 |
| --- | --- |
| space | 연속 모드 시작/정지 |
| `n` | 다음 phase를 한 번 실행하고 정지 |
| ↑ / `W`, ↓ / `S` | base ±0.5mm |
| → / `D`, ← / `A` | shift ±0.5mm |
| `+` / `-` | lift ±0.5mm |
| `1` / `2` | shift duration ∓/±10ms |
| `3` / `4` | lift duration ∓/±10ms |
| `5` / `6` | plant duration ∓/±10ms |
| `[` / `]` | lift 정점 hold ∓/±10ms (0–1000ms) |
| `;` / `'` | plant hold ∓/±10ms (0–1000ms) |
| `m` | 정지 상태에서 PHASE6 ↔ BRUTON 전환 |
| `,` / `.` | lean ∓/±0.5° |
| `k` | 육안으로 확인한 발-뜸을 현재 phase·높이·roll과 함께 기록 |
| `r` | 표시용 IMU roll/pitch 기준 재설정 |
| `v` | 파라미터, phase 목표, 도달 가능 여부, x 결합, 기록 출력 |
| `0` | 정지 후 base 평행 stand로 복귀 |
| `q` | 종료 요약 후 base 평행 stand로 복귀, 줄 단위 콘솔 복귀 |
| `!` | 즉시 E-STOP |

BRUTON 패턴에서는 `space`가 별도의 양다리 dual-timer 동작을 시작/정지한다.
오른다리가 먼저 시작하고, 좌우 높이를 독립적으로 보간한다. `shift`는
사용하지 않는다. `n`, 좌우 방향키/A·D, `5`/`6`, hold 키는 동작하지 않고
안내만 출력한다. 위/아래는 base, `+`/`-`는 lift, `,`/`.`는 lean이며,
`1`/`2`는 step time, `3`/`4`는 leg time을 각각 10ms씩 조정한다.
`i`로 pitch 기반의 미세한 시간 변조를 켜거나 끌 수 있다(기본 OFF).
IMU는 자동 정지나 스윙 판정에 사용하지 않는다. BRUTON 정지 시 양다리는
2초 동안 base로 복귀한다. 다른 높이에서 시작하려 하면 먼저 `0`으로
base에 복귀해야 한다.

base는 85–104mm, shift는 0–10mm, lift는 0–15mm다. 개별 phase 목표가
기구학 범위 또는 관절 한계 밖이면 `v`에 `UNREACHABLE`로 표시된다. 그런
설정으로는 연속 모드를 시작할 수 없다. 동작 중에 새 설정으로 다음 phase가
거부되면 마지막 전송 목표를 유지하고, 연속 모드를 자동 정지하지 않는다.

## 6개 phase

기본값은 base=96.5mm, shift=3mm, lift=0mm,
shift/lift/plant duration=150/140/140ms, lift/plant hold=140/0ms다.
hold를 둘 다 0으로 설정하면 기존 6-phase 타이밍과 같다. `rock` 진입만으로 연속 모드가
시작되지는 않는다.

| # | phase | 왼쪽 높이 | 오른쪽 높이 | duration |
| --- | --- | ---: | ---: | --- |
| 0 | SHIFT_R | base+shift | base−shift | shift |
| 1 | LIFT_L | base+shift−lift | base−shift | lift |
| 2 | PLANT_L | base+shift | base−shift | plant |
| 3 | SHIFT_L | base−shift | base+shift | shift |
| 4 | LIFT_R | base−shift | base+shift−lift | lift |
| 5 | PLANT_R | base−shift | base+shift | plant |

각 phase는 **직전 실제 전송 높이**에서 새 목표 높이까지 독립 duration으로
보간한다. `n` 단계 모드에서는 완료 시 phase·발 x·직전 phase 대비 Δx를
한 줄 출력한다. 지지발 Δx가 크면 바닥에 붙은 발이 몸통을 앞뒤로 밀 수 있다.
연속 모드에서는 phase마다 출력하지 않고 여섯 phase가 끝날 때마다 한 줄의
roll/pitch 범위와 지지발 최대 Δx를 출력한다.

LIFT 정점 hold가 끝날 때마다 해당 다리의 knee 서보 하나를 읽어 명령한
다리 접힘량 대비 실제 접힘량을 출력한다. BRUTON은 다리별 state 1→2에서
동일하게 측정한다. `v`에는 최근 10회 추종률 평균·최소, 종료 요약에는
전체 평균이 나온다. 이 값은 **다리가 접힌 정도**이지 발의 지면
클리어런스나 실제 발-뜸 판정이 아니다. 읽기 실패 시 해당 측정만 건너뛴다.

BRUTON 기본값은 lift=6.5mm, step time=250ms, leg time=140ms이다.
각 다리는 접기 → 짧은 높이 유지 → 펴기 → 긴 높이 유지의 4-state를
독립적으로 수행한다. x 이동이나 IK는 추가하지 않았다.

평행 다리는 발바닥 각도를 유지하는 대신 높이에 따라 발 x가 바뀐다.
`foot_x = L1 sin(a) − L2 sin(−ANKLE_FIXED)`이며 base 96.5mm 부근에서는
높이 1mm당 약 1.29mm의 x 이동이 생긴다. `v`에 이 결합 비율을 표시한다.
lean의 양수는 상체를 앞으로 숙이는 방향이며, 사용 중 IMU pitch가 반대로
간다면 부호를 다시 확인해야 한다. PHASE6에서 IMU는 표시용이며,
BRUTON에서만 `i`를 켰을 때 pitch가 타이밍을 미세조정한다. 어느 패턴에서도
IMU로 자동 정지하거나 발-뜸을 판정하지 않는다.

속도 가드는 400°/s의 최후 방어선이다. 발동 시 목표를 마지막으로 성공한
전송값에 고정해 경고의 무한 반복을 막고 연속 모드를 정지한다. 서보 speed와
acceleration raw 설정은 둘 다 `0`이다.

## 권장 실험 순서

1. `status`로 여섯 서보의 응답과 각도를 확인하고, 로봇을 받친 채 `arm`한다.
2. `stand 96.5 0`으로 발 평행을 확인한다. 뒤로 기울면 rock 모드의 `.`로
   lean을 올리면서 `v`의 상대 pitch가 0 근처로 오는지 관찰한다.
3. `rock`에 들어간 뒤 lift=0, shift=3 상태로 `n`을 눌러 SHIFT_R/SHIFT_L의
   좌우 기울기를 확인한다.
4. space로 연속 rocking을 시작해 roll이 양쪽으로 진동하는지 확인한다.
5. 정지 후 `+`로 lift를 올리고 `n`으로 LIFT phase에서 발이 뜨는지 본다.
   눈으로 확인했을 때 `k`로 기록한다.
6. 뜨지 않으면 두 방향을 비교한다: shift를 0에 가깝게 줄이고 lift
   duration을 100–150ms로 줄이는 동적 방식, 또는 shift와 각 duration을
   늘리는 준정적 방식이다.
7. 출력의 지지발 Δx가 크면 base를 낮춰 앞뒤 결합을 줄인다.

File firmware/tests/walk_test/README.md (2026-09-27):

# TILT walk test

`walk_test`는 James Bruton의 YouCanBuildBiPed / Robot003 보행 구조를 TILT의
검증된 서보·기구학·IMU 컴포넌트 위에 최소 구성으로 옮긴 독립 ESP-IDF
프로젝트다. 기존 `pose_test`나 다른 테스트 프로젝트와 연결되지 않는다.

핵심 차이는 다리를 최대 신전에 가깝게 펴지 않는다는 점이다. 기본 긴 다리
96.5 mm와 짧은 다리 90.0 mm는 TILT의 유효 최대 도달 거리 109.5 mm 대비
각각 약 88%, 82%다. 보행은 10 ms 주기로 발 위치 `(x, z)`를 선형 보간한 뒤
매 루프 IK를 풀어 여섯 축을 동기 전송한다.

## 배선과 물리적 안전

- ESP32-S3 `GPIO17 TX → Adapter TXD`, `GPIO18 RX → Adapter RXD`로 직결한다.
- Waveshare Bus Servo Adapter (A)의 UART 점퍼를 A에 둔다.
- 서보 ID는 `11, 12, 13, 21, 22, 23`, 통신 속도는 1 Mbps다.
- 서보는 별도 전원을 사용하고 ESP32와 GND를 공유한다.
- 처음에는 로봇을 바닥에 세우되 양손으로 바로 받칠 준비를 한다.
- 서보 전원을 즉시 끊을 수단을 항상 손 닿는 곳에 둔다. 콘솔의 `!`는 UART
  통신이나 전원 자체가 끊어진 상황을 대신할 수 없다.
- 부팅 시에는 항상 `DISARMED`, 토크 OFF이며 자동으로 움직이지 않는다.

## 빌드와 실행

```bash
source /Users/jae/esp/esp-idf/export.sh
cd firmware/tests/walk_test
idf.py set-target esp32s3
idf.py build
idf.py -p /dev/cu.usbmodemXXXX flash monitor
```

권장 순서는 다음과 같다.

1. `status`로 여섯 서보의 응답과 현재 논리 각도를 확인한다.
2. 로봇을 손으로 안전하게 받친 채 `arm`을 입력한다. 현재 여섯 위치를 먼저
   hold goal로 기록한 뒤에만 토크가 켜진다.
3. 필요하면 `joint <name> <-5..+5>`로 각 관절 방향을 작은 각도로 확인한다.
4. `stand`로 기본 긴 다리 높이를 확인한다.
5. `walk`를 입력하면 먼저 같은 stand 자세로 2초 동안 이동하고, 정지 상태의
   walk 모드에 들어간다. 자세를 받친 뒤 space로 보행을 시작한다.

## 보행 구조

`stepTime`(기본 250 ms)은 왼쪽과 오른쪽 다리의 트리거를 번갈아 만들고,
각 다리의 독립 `legTime`(기본 140 ms)은 아래 네 상태를 진행한다. 두 시간을
서로 배수로 맞추지 않는 것이 의도된 위상 구성이다.

1. 트리거를 기다리다가 `z = short`로 다리만 짧게 한다.
2. `x = -legx`로 발만 이동한다.
3. `z = long`으로 다리만 길게 한다.
4. `x = +legx`로 발만 반대편으로 이동하고 대기 상태로 돌아간다.

각 상태는 `x` 또는 `z` 하나만 바꾼다. IK에 전달할 때는 두 다리에 항상
`legx × 0.25`의 전방 바이어스를 더한다. `legx`는 양수와 음수를 모두 허용하므로
실기에서 어느 부호가 전진인지 확인할 수 있다.

## 명령

줄 단위 명령:

| 명령 | 동작 |
| --- | --- |
| `help` | 명령 목록 출력 |
| `status` | 여섯 축 ping, raw tick, 논리 각도 출력 |
| `arm` / `disarm` | 현재 자세를 캡처한 뒤 토크 ON / 토크 OFF |
| `recover` | E-STOP에서 DISARMED로 복구; 이후 다시 `arm` 필요 |
| `!` | 어느 모드에서든 즉시 E-STOP 및 토크 OFF 요청 |
| `home` | ADR-008 zero pose로 2초 보간 이동 |
| `stand` | 양발을 현재 `long_leg` 높이에 둠 |
| `joint <name> <-5..+5>` | 단일 관절 상대 조그 |
| `walk` | stand 자세로 이동한 뒤 문자 입력 walk 모드 진입 |

walk 모드 키:

| 키 | 동작 |
| --- | --- |
| space | 보행 시작/정지. 정지하면 `legx=0`, 양다리는 long으로 복귀 |
| → / `D`, ← / `A` | `legx`를 ±1 mm 조정(범위 -15~+15 mm) |
| ↑ / `W`, ↓ / `S` | long과 short를 함께 ±0.5 mm 조정 |
| `+` / `-` | `long-short` 차이를 ±0.5 mm 조정 |
| `[` / `]` | `stepTime`을 ∓/±10 ms 조정 |
| `{` / `}` | `legTime`을 ∓/±10 ms 조정 |
| `i` | IMU pitch 기반 타이밍 변조 ON/OFF(기본 OFF) |
| `0` | `legx=0` |
| `r` | 표시용 roll/pitch 기준 재설정 |
| `v` | 파라미터, 신전률, IMU, 거부 횟수 출력 |
| `q` | 결과 요약을 출력하고 home으로 복귀 |
| `!` | 즉시 E-STOP |

## IMU와 안전 가드

IMU는 roll/pitch 표시와 선택적 리듬 변조에만 사용한다. `i`를 켜면 절대 pitch
크기에 따라 step time은 240~260 ms, leg time은 130~150 ms 범위에서만
미세 조정된다. IMU 값으로 스윙 다리를 고르거나 자세를 보상하거나 보행을 자동
정지하지 않는다. IMU를 읽을 수 없으면 변조만 꺼지고 보행은 설정된 기본 시간으로
계속된다.

도달 불가 또는 관절 한계 밖의 IK 목표는 클램프해서 보내지 않고 마지막 전송
목표를 유지한다. 거부가 반복되어도 자동 정지하지 않으며 횟수만 집계한다.
300 deg/s 속도 가드는 최후 방어선이다. 발동하면 한 번 경고하고 보행을 정지한 뒤
마지막으로 실제 전송된 목표를 유지한다.

한 보행 사이클(좌우가 각각 한 번 상태 4까지 완료)마다만 한 줄을 출력한다. 종료
요약의 roll/pitch 범위는 관측 정보이며 이동 거리 추정에는 쓰지 않는다. 실제
전진량은 바닥에 표시를 두고 직접 재고, 완료 사이클 수로 나누어 비교한다.

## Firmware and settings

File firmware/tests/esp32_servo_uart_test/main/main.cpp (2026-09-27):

// ESP32-S3 + Waveshare Bus Servo Adapter A (STS3215 x6) UART 제어 테스트
// - 절대 각도로 바로 점프하지 않고, 키를 누를 때마다 정해진 스텝만큼만 증분 이동
// - 스텝 크기는 2단계: 정밀(1 tick = 0.088도) / 빠름(기본 20 tick 약 1.76도), 'm' 키로 토글
// - Enter 없이 키 1개 입력마다 즉시 반응 (idf.py monitor는 터미널을 raw 모드로 돌려서
//   키 입력을 누르는 즉시 바이트 단위로 전달해줌)
//
// 배선 (주의: 이 보드는 일반적인 UART 크로스 연결이 아니라 스트레이트로 묶는다):
//   ESP32-S3 GPIO17 (TX) -> Adapter TXD
//   ESP32-S3 GPIO18 (RX) -> Adapter RXD
//   보드의 점퍼는 A 위치(UART 모드)
//   GND 공통, 서보 전원은 별도 파워서플라이 사용 (ESP32 5V로 직접 구동 금지)
//
// 키 매핑 (QWERTY 두 줄, 윗줄 +/아랫줄 -):
//   서보 11 : q(+) / a(-)
//   서보 12 : w(+) / s(-)
//   서보 13 : e(+) / d(-)
//   서보 21 : r(+) / f(-)
//   서보 22 : t(+) / g(-)
//   서보 23 : y(+) / h(-)
//   m : 스텝 모드 토글 (정밀 <-> 빠름)
//   p : 서보 ID 스캔
//   b : 보레이트 자동 스캔
//   스페이스바 : 비상정지 (6개 서보 토크 전체 OFF)

#include <cstdio>
#include <cstring>
#include <cctype>

#include "freertos/FreeRTOS.h"
#include "freertos/task.h"
#include "driver/uart.h"
#include "driver/gpio.h"
#include "driver/usb_serial_jtag.h"
#include "esp_log.h"

static const char *TAG = "servo_test";

// ---------------- 서보 버스 UART 설정 (STS3215 x6) ----------------
#define SERVO_UART_NUM      UART_NUM_1
#define SERVO_UART_TX_PIN   GPIO_NUM_17
#define SERVO_UART_RX_PIN   GPIO_NUM_18
#define SERVO_UART_BAUD     1000000   // STS3215 공장 출하 기본 보레이트(1Mbps)

// ---------------- 콘솔(키보드 입력) 설정 ----------------
// 이 보드는 별도 USB-UART 브릿지 칩 없이 ESP32-S3 내장 USB-Serial/JTAG 컨트롤러로
// 맥북과 통신한다 (esptool 연결 로그의 "USB mode: USB-Serial/JTAG"가 그 증거).
// 그래서 UART_NUM_0(GPIO43/44) 물리 핀이 아니라 usb_serial_jtag 드라이버로 입력을 읽어야 한다.

// ---------------- STS/SCS 버스 서보 프로토콜 ----------------
// 패킷 구조: [0xFF][0xFF][ID][LEN][INSTR][PARAMS...][CHECKSUM]
// LEN = INSTR(1) + PARAMS(N) + CHECKSUM(1)
// CHECKSUM = ~(ID + LEN + INSTR + sum(PARAMS)) & 0xFF
//
// 주의: 아래 컨트롤 테이블 주소는 Feetech STS 계열에서 널리 쓰이는 값입니다.
// 실제 동작이 다르면 STS3215 데이터시트/메모리 맵으로 주소를 다시 확인하세요.
#define INST_PING             0x01
#define INST_READ             0x02
#define INST_WRITE            0x03
#define ADDR_TORQUE_ENABLE    40   // 0x28, 1 byte
#define ADDR_GOAL_POSITION    42   // 0x2A, 2 byte (little endian)
#define ADDR_GOAL_SPEED       46   // 0x2E, 2 byte (0 = 최대 속도)
#define ADDR_PRESENT_POSITION 56   // 0x38, 2 byte (little endian)

// 최소 분해능 1 tick = 0.088도 (4096 step / 360도, STS3215 12bit 엔코더 기준)
#define POS_MIN 0
#define POS_MAX 4095

// ---------------- 스텝 모드 (2단계) ----------------
// FINE   : 각도 정밀 캘리브레이션용. 한 번에 1 tick(0.088도)만 움직임.
// COARSE : 구동 테스트용. 한 번에 COARSE_STEP tick씩 움직임.
#define FINE_STEP    1     // 0.088도
#define COARSE_STEP  20    // 약 1.76도 (더 빠르게 하려면 이 값만 키우면 됨)

// 서보에 실어 보내는 GOAL_SPEED (0 = 서보 최대 속도)
// 스텝이 작을 때는 속도를 낮춰도 체감이 거의 없어 정밀 모드는 0으로 둔다.
// 빠름 모드에서 움직임이 너무 급하면 COARSE_GOAL_SPEED를 1000 정도로 올려 제한할 수 있다.
#define FINE_GOAL_SPEED    0
#define COARSE_GOAL_SPEED  0

static bool s_coarse_mode = false; // false = 정밀 모드(기본), true = 빠름 모드

static int current_step()              { return s_coarse_mode ? COARSE_STEP : FINE_STEP; }
static uint16_t current_speed()        { return s_coarse_mode ? COARSE_GOAL_SPEED : FINE_GOAL_SPEED; }
static const char *current_mode_name() { return s_coarse_mode ? "빠름(COARSE)" : "정밀(FINE)"; }

// 'p' 키로 실행하는 ID 스캔 범위 (필요하면 넓혀도 됨, 최대 253)
#define SCAN_ID_MIN 0
#define SCAN_ID_MAX 253

// 'b' 키로 실행하는 보레이트 자동 스캔 후보 (STS 계열이 지원하는 흔한 값들)
static const uint32_t BAUD_CANDIDATES[] = {
    1000000, 500000, 250000, 128000, 115200, 76800, 57600, 38400, 19200, 9600
};

// 사용할 서보 ID: 왼쪽 다리(11,12,13) / 오른쪽 다리(21,22,23)
static const uint8_t SERVO_IDS[6] = {11, 12, 13, 21, 22, 23};
static uint16_t s_cur_pos[6]; // 각 서보의 현재(로컬에서 추적하는) 목표 위치

// 키 -> (서보 인덱스, 방향) 매핑
struct KeyMap { char key; int servo_idx; int8_t dir; };
static const KeyMap KEY_MAP[12] = {
    {'q', 0, +1}, {'a', 0, -1}, // 서보 11
    {'w', 1, +1}, {'s', 1, -1}, // 서보 12
    {'e', 2, +1}, {'d', 2, -1}, // 서보 13
    {'r', 3, +1}, {'f', 3, -1}, // 서보 21
    {'t', 4, +1}, {'g', 4, -1}, // 서보 22
    {'y', 5, +1}, {'h', 5, -1}, // 서보 23
};

static void servo_uart_init() {
    uart_config_t cfg = {};
    cfg.baud_rate = SERVO_UART_BAUD;
    cfg.data_bits = UART_DATA_8_BITS;
    cfg.parity    = UART_PARITY_DISABLE;
    cfg.stop_bits = UART_STOP_BITS_1;
    cfg.flow_ctrl = UART_HW_FLOWCTRL_DISABLE;
    cfg.source_clk = UART_SCLK_DEFAULT;

    ESP_ERROR_CHECK(uart_driver_install(SERVO_UART_NUM, 512, 512, 0, NULL, 0));
    ESP_ERROR_CHECK(uart_param_config(SERVO_UART_NUM, &cfg));
    ESP_ERROR_CHECK(uart_set_pin(SERVO_UART_NUM, SERVO_UART_TX_PIN, SERVO_UART_RX_PIN,
                                  UART_PIN_NO_CHANGE, UART_PIN_NO_CHANGE));
}

// 콘솔 입력을 USB-Serial/JTAG 드라이버에서 직접 읽는다 (fgets처럼 Enter를 기다리지 않음).
// IDF 콘솔이 부팅 시 이미 이 드라이버를 설치해뒀을 수 있으므로, 이미 설치된 상태(ESP_ERR_INVALID_STATE)는
// 에러로 취급하지 않고 그냥 기존 드라이버를 그대로 사용한다.
static void console_input_init() {
    usb_serial_jtag_driver_config_t cfg = USB_SERIAL_JTAG_DRIVER_CONFIG_DEFAULT();
    esp_err_t err = usb_serial_jtag_driver_install(&cfg);
    if (err != ESP_OK && err != ESP_ERR_INVALID_STATE) {
        ESP_ERROR_CHECK(err);
    }
}

// 공통 WRITE 패킷 전송 (addr에서 시작하는 data_len 바이트를 씀)
static void servo_write(uint8_t id, uint8_t addr, const uint8_t *data, uint8_t data_len) {
    uint8_t param_len = data_len + 1; // addr(1) + data
    uint8_t len = param_len + 2;      // INSTR + PARAMS + CHECKSUM

    uint8_t pkt[6 + 8];
    int idx = 0;
    pkt[idx++] = 0xFF;
    pkt[idx++] = 0xFF;
    pkt[idx++] = id;
    pkt[idx++] = len;
    pkt[idx++] = INST_WRITE;
    pkt[idx++] = addr;

    uint32_t sum = id + len + INST_WRITE + addr;
    for (int i = 0; i < data_len; ++i) {
        pkt[idx++] = data[i];
        sum += data[i];
    }
    pkt[idx++] = (uint8_t)(~sum);

    uart_write_bytes(SERVO_UART_NUM, (const char *)pkt, idx);
}

static void servo_torque_enable(uint8_t id, bool on) {
    uint8_t v = on ? 1 : 0;
    servo_write(id, ADDR_TORQUE_ENABLE, &v, 1);
}

static void servo_write_pos(uint8_t id, uint16_t position, uint16_t speed) {
    uint8_t data[4] = {
        (uint8_t)(position & 0xFF),
        (uint8_t)((position >> 8) & 0xFF),
        (uint8_t)(speed & 0xFF),
        (uint8_t)((speed >> 8) & 0xFF),
    };
    servo_write(id, ADDR_GOAL_POSITION, data, sizeof(data));
}

// 현재 위치 READ. 응답을 받으면 true, 못 받으면 false.
// 응답 패킷: [0xFF][0xFF][ID][LEN][ERR][DATA...][CHECKSUM]
static bool servo_read_pos(uint8_t id, uint16_t *out_pos) {
    uint8_t param[2] = { ADDR_PRESENT_POSITION, 2 };
    uint8_t len = sizeof(param) + 2;
    uint8_t pkt[8];
    int idx = 0;
    pkt[idx++] = 0xFF;
    pkt[idx++] = 0xFF;
    pkt[idx++] = id;
    pkt[idx++] = len;
    pkt[idx++] = INST_READ;
    uint32_t sum = id + len + INST_READ;
    for (uint8_t b : param) { pkt[idx++] = b; sum += b; }
    pkt[idx++] = (uint8_t)(~sum);

    uart_flush_input(SERVO_UART_NUM);
    uart_write_bytes(SERVO_UART_NUM, (const char *)pkt, idx);

    uint8_t resp[16];
    int got = uart_read_bytes(SERVO_UART_NUM, resp, sizeof(resp), pdMS_TO_TICKS(50));
    if (got < 8) return false;

    for (int i = 0; i <= got - 8; ++i) {
        if (resp[i] == 0xFF && resp[i + 1] == 0xFF && resp[i + 2] == id) {
            uint8_t pos_l = resp[i + 5];
            uint8_t pos_h = resp[i + 6];
            *out_pos = (uint16_t)(pos_l | (pos_h << 8));
            return true;
        }
    }
    return false;
}

// PING: 해당 ID의 서보가 버스에 붙어있으면 true.
// 응답 패킷: [0xFF][0xFF][ID][LEN][ERR][CHECKSUM] (파라미터 없음)
static bool servo_ping(uint8_t id) {
    uint8_t len = 2; // INSTR + CHECKSUM
    uint8_t pkt[6];
    int idx = 0;
    pkt[idx++] = 0xFF;
    pkt[idx++] = 0xFF;
    pkt[idx++] = id;
    pkt[idx++] = len;
    pkt[idx++] = INST_PING;
    uint32_t sum = id + len + INST_PING;
    pkt[idx++] = (uint8_t)(~sum);

    uart_flush_input(SERVO_UART_NUM);
    uart_write_bytes(SERVO_UART_NUM, (const char *)pkt, idx);

    uint8_t resp[8];
    int got = uart_read_bytes(SERVO_UART_NUM, resp, sizeof(resp), pdMS_TO_TICKS(15));
    if (got < 6) return false; // 최소 응답 길이: 0xFF 0xFF ID LEN ERR CHK

    for (int i = 0; i <= got - 6; ++i) {
        if (resp[i] == 0xFF && resp[i + 1] == 0xFF && resp[i + 2] == id) {
            return true;
        }
    }
    return false;
}

// SCAN_ID_MIN ~ SCAN_ID_MAX 범위를 순회하며 응답하는 서보 ID를 출력하고 개수를 반환한다.
static int scan_servo_ids_quiet() {
    int found = 0;
    for (int id = SCAN_ID_MIN; id <= SCAN_ID_MAX; ++id) {
        if (servo_ping((uint8_t)id)) {
            printf("    -> 응답 있음: ID %d\n", id);
            found++;
        }
        vTaskDelay(pdMS_TO_TICKS(5));
    }
    return found;
}

// SCAN_ID_MIN ~ SCAN_ID_MAX 범위를 순회하며 실제로 응답하는 서보 ID를 출력한다.
static void scan_servo_ids() {
    printf("\n=== 서보 ID 스캔 시작 (ID %d~%d) ===\n", SCAN_ID_MIN, SCAN_ID_MAX);
    int found = scan_servo_ids_quiet();
    printf("=== 스캔 완료: %d개 서보 응답 ===\n\n", found);
    if (found == 0) {
        printf("응답한 서보가 하나도 없습니다. 서보 전원/배선/보레이트를 다시 확인하세요.\n\n");
    }
}

// 여러 보레이트를 순차적으로 바꾸며 각 보레이트에서 ID 스캔을 돌려본다.
// 응답이 있는 보레이트를 찾으면 그 보레이트를 유지한 채 멈추고, 못 찾으면 원래 설정으로 되돌린다.
static void scan_baud_rates() {
    printf("\n=== 보레이트 자동 스캔 시작 ===\n");
    for (uint32_t baud : BAUD_CANDIDATES) {
        printf("  [%u bps] 시도 중...\n", (unsigned)baud);
        uart_set_baudrate(SERVO_UART_NUM, baud);
        vTaskDelay(pdMS_TO_TICKS(20)); // 보레이트 전환 안정화 대기

        int found = scan_servo_ids_quiet();
        if (found > 0) {
            printf("=== 보레이트 %u bps에서 %d개 응답 발견! 이 보레이트로 계속 사용합니다. ===\n", (unsigned)baud, found);
            printf("    -> main.cpp의 SERVO_UART_BAUD를 %u로 고치면 다음 부팅부터 바로 적용됩니다.\n\n", (unsigned)baud);
            return;
        }
    }

    printf("=== 모든 후보 보레이트에서 응답 없음. 원래 설정(%u bps)으로 되돌립니다. ===\n", (unsigned)SERVO_UART_BAUD);
    printf("이 경우는 보레이트 문제가 아니라 배선/전원/ID 설정 쪽을 다시 보셔야 합니다.\n\n");
    uart_set_baudrate(SERVO_UART_NUM, SERVO_UART_BAUD);
}

static uint16_t clamp_pos(int32_t v) {
    if (v < POS_MIN) return POS_MIN;
    if (v > POS_MAX) return POS_MAX;
    return (uint16_t)v;
}

static void print_help() {
    printf("\n서보 증분 제어 (Enter 불필요, 키 누르는 즉시 반응)\n");
    printf("  q/a : 서보 11  +/-\n");
    printf("  w/s : 서보 12  +/-\n");
    printf("  e/d : 서보 13  +/-\n");
    printf("  r/f : 서보 21  +/-\n");
    printf("  t/g : 서보 22  +/-\n");
    printf("  y/h : 서보 23  +/-\n");
    printf("  m : 스텝 모드 토글 (정밀 %d tick / 빠름 %d tick)\n", FINE_STEP, COARSE_STEP);
    printf("  p : ID 스캔 (%d~%d 범위, 실제 응답하는 서보 ID 찾기)\n", SCAN_ID_MIN, SCAN_ID_MAX);
    printf("  b : 보레이트 자동 스캔 (여러 보레이트를 순회하며 서보가 응답하는 값 찾기)\n");
    printf("  space : 비상정지 (전체 토크 OFF)\n");
    printf("현재 모드: %s (1회 %d tick = %.3f deg)\n\n",
           current_mode_name(), current_step(), current_step() * 360.0f / 4096.0f);
}

// 스텝 모드 토글 (정밀 <-> 빠름)
static void toggle_step_mode() {
    s_coarse_mode = !s_coarse_mode;
    printf(">> 스텝 모드: %s (1회 %d tick = %.3f deg)\n",
           current_mode_name(), current_step(), current_step() * 360.0f / 4096.0f);
}

// 모든 서보 토크 OFF (비상정지)
static void emergency_stop() {
    for (uint8_t id : SERVO_IDS) {
        servo_torque_enable(id, false);
    }
    printf("!! 비상정지: 전체 토크 OFF !!\n");
}

// ---------------- 키보드(시리얼 콘솔) 1바이트 입력 처리 ----------------
static void console_task(void *arg) {
    print_help();

    uint8_t ch;
    while (true) {
        int len = usb_serial_jtag_read_bytes(&ch, 1, pdMS_TO_TICKS(50));
        if (len <= 0) {
            continue;
        }

        if (ch == ' ') {
            emergency_stop();
            continue;
        }

        char key = (char)tolower(ch);

        if (key == 'm') {
            toggle_step_mode();
            continue;
        }

        if (key == 'p') {
            scan_servo_ids();
            continue;
        }

        if (key == 'b') {
            scan_baud_rates();
            continue;
        }

        for (const auto &km : KEY_MAP) {
            if (km.key == key) {
                int idx = km.servo_idx;
                int32_t delta = (int32_t)km.dir * current_step();
                uint16_t new_pos = clamp_pos((int32_t)s_cur_pos[idx] + delta);
                s_cur_pos[idx] = new_pos;
                servo_write_pos(SERVO_IDS[idx], new_pos, current_speed());
                printf("servo %d : pos=%u (%.3f deg) [%s]\n",
                       SERVO_IDS[idx], new_pos, new_pos * 360.0f / 4096.0f,
                       current_mode_name());
                break;
            }
        }
        // 매핑 안 된 키(엔터, 방향키 등)는 무시
    }
}

extern "C" void app_main(void) {
    servo_uart_init();
    console_input_init();

    // 부팅 시 절대 위치 명령은 보내지 않는다.
    // 각 서보의 실제 현재 위치를 READ로 확인해서 로컬 기준값으로만 저장하고,
    // 그 값에서부터 스텝 단위로만 움직이도록 해서 초기 스냅(급격한 위치 점프)을 방지한다.
    for (int i = 0; i < 6; ++i) {
        uint16_t pos = 2048; // 읽기 실패 시 기본값(중앙, 약 180도)
        if (servo_read_pos(SERVO_IDS[i], &pos)) {
            ESP_LOGI(TAG, "servo %d 현재 위치 읽음: pos=%u", SERVO_IDS[i], pos);
        } else {
            ESP_LOGW(TAG, "servo %d 위치 READ 실패 -> 임시로 중앙값(2048) 가정. "
                           "첫 스텝 이동 시 실제 위치와 다를 수 있으니 확인 필요", SERVO_IDS[i]);
        }
        s_cur_pos[i] = pos;
        vTaskDelay(pdMS_TO_TICKS(10));
    }

    for (uint8_t id : SERVO_IDS) {
        servo_torque_enable(id, true);
        vTaskDelay(pdMS_TO_TICKS(10));
    }
    ESP_LOGI(TAG, "6개 서보 토크 ON 완료 (ID: 11,12,13,21,22,23)");

    xTaskCreate(console_task, "console_task", 4096, NULL, 5, NULL);
}

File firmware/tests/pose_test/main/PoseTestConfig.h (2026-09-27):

#pragma once

#include <cstdint>

#include "tilt_config.h"

namespace tilt_pose_test {

constexpr float kBodyHeightMinMm = 92.0f;
constexpr float kBodyHeightMaxMm = 107.0f;
constexpr float kBodyXMinMm = -20.0f;
constexpr float kBodyXMaxMm = +20.0f;
constexpr float kIkFineStepMm = 0.5f;
constexpr float kIkCoarseStepMm = 2.0f;
constexpr std::uint32_t kIkStepDurationMs = 150;

// Rocking test: differential leg length while body_x remains zero.
constexpr float kRockDeltaMaxMm = 24.0f;
constexpr float kRockFineStepMm = 0.5f;
constexpr float kRockCoarseStepMm = 2.0f;
constexpr std::uint32_t kRockStepDurationMs = 300;
constexpr float kRockSweepStartMm = 0.0f;
constexpr float kRockSweepEndMm = 14.0f;
constexpr float kRockSweepStepMm = 1.0f;
constexpr std::uint32_t kRockSweepHoldMs = 1500;
constexpr std::uint32_t kRockAlternatePeriodMs = 1000;
constexpr std::uint32_t kRockAlternatePeriodMinMs = 150;
constexpr std::uint32_t kRockAlternatePeriodMaxMs = 2000;
constexpr std::uint32_t kRockAlternatePeriodStepMs = 50;
constexpr float kRockRollAbortDeg = 20.0f;
constexpr float kRockRecommendedMarginMm = 1.5f;

constexpr std::uint32_t kPoseDurationMs = 3000;
constexpr std::uint32_t kJointDurationMs = 1000;

constexpr float kMaxJointVelocityDegS = 180.0f;
constexpr float kDurationSafetyFactor = 1.3f;
constexpr std::uint32_t kMinMoveDurationMs = 60;
constexpr float kMaxJointStepDeg = kMaxJointVelocityDegS *
                                   (tilt::CONTROL_PERIOD_MS / 1000.0f);
constexpr float kMaxJointStepRad = kMaxJointStepDeg * tilt::DEG2RAD;
constexpr float kMaxJogStepDeg = 5.0f;
constexpr std::uint16_t kServoSpeedRaw = 0;
constexpr std::uint8_t kServoAcceleration = 0;

// IMU compensation shared by stand, rocking, and walk modes.
constexpr float kCompKpPitchDefault = 2.0f;
constexpr float kCompKpPitchMax = 10.0f;
constexpr float kCompKpPitchStep = 0.5f;
constexpr float kCompBodyXMaxMm = 15.0f;
constexpr float kCompLpfAlpha = 0.30f;
constexpr float kCompLpfAlphaStep = 0.05f;

// Slow, cycle-boundary roll compensation for rocking mode.
constexpr float kCompKrCenterDefault = 0.3f;
constexpr float kCompDeltaBiasMaxMm = 4.0f;
constexpr float kCompRollTargetAmpDeg = 4.0f;
constexpr float kCompKaAmpDefault = 0.05f;
constexpr float kCompDeltaScaleMax = 1.8f;

constexpr float kCompAbortPitchDeg = 20.0f;
constexpr float kCompAbortRollDeg = 20.0f;

constexpr float kStepTestBodyXMm = 8.0f;
constexpr std::uint32_t kStepTestHoldMs = 500;
constexpr std::uint32_t kStepTestRecordMs = 2000;
constexpr float kStepTestSettleDeg = 1.0f;

constexpr std::uint32_t kStatusPrintPeriodMs = 200;

// Walk: open-loop rocking.
constexpr float kWalkDeltaDefaultMm = 14.0f;
constexpr float kWalkDeltaStepMm = 1.0f;
constexpr std::uint32_t kWalkRockPeriodMs = 300;
constexpr std::uint32_t kWalkRockPeriodMinMs = 150;
constexpr std::uint32_t kWalkRockPeriodMaxMs = 800;
constexpr std::uint32_t kWalkRockPeriodStepMs = 25;

// Walk: explicit swing-foot lift.
constexpr float kWalkLiftDefaultMm = 0.0f;
constexpr float kWalkLiftMaxMm = 14.0f;
constexpr float kWalkLiftStepMm = 1.0f;

// Walk: roll-triggered swing with hysteresis and time bounds.
constexpr float kWalkRollTriggerDeg = 2.5f;
constexpr float kWalkRollReleaseDeg = 1.2f;
constexpr float kWalkRollTriggerStepDeg = 0.25f;
constexpr std::uint32_t kWalkSwingMinMs = 80;
constexpr std::uint32_t kWalkSwingMaxMs = 400;

// Walk: fore/aft foot motion.
constexpr float kWalkLegxDefaultMm = 0.0f;
constexpr float kWalkLegxMaxMm = 20.0f;
constexpr float kWalkLegxStepMm = 1.0f;
constexpr std::uint32_t kWalkMaxConsecutiveRejects = 3;

struct PosePreset {
    const char* name;
    float deg[tilt::NUM_JOINTS];
};

// Only home is an ADR-008-confirmed pose. The others are hardware-test drafts.
constexpr PosePreset kPoses[] = {
    {"home",      {0, -20, +20,  0, -20, +20}},
    {"tall",      {0, -15, +15,  0, -15, +15}},
    {"crouch",    {0, -30, +35,  0, -30, +35}},
    {"yaw-left",  {+5, -20, +20, +5, -20, +20}},
    {"yaw-right", {-5, -20, +20, -5, -20, +20}},
};

}  // namespace tilt_pose_test

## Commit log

2026-09-16 chore(CAD): add 3mf files
    [tilt-calf-foot.3mf, tilt-hip-pitch-housing.3mf, tilt-hip-pitch-mount.3mf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]
2026-09-16 feat(tools): add python-based servo setting tool
2026-09-19 test(firmware): waveshare UART connection study
2026-09-19 test(firmware): modify servo control method safer
2026-09-19 feat(firmware): add motor ID detection and control speed mode switch
2026-09-20 feat(firmware): add sts3215 servo control components
2026-09-20 feat(tools): add servo tools via UART
2026-09-20 feat(firmware): add Forward & Inverse Kinematics calculator
2026-09-20 feat(tests): add servo low level control test codes
2026-09-20 feat(firmware): optimize pose test and adapt servo calibration tool
2026-09-20 feat(firmware): add imu compensation and try to swing
